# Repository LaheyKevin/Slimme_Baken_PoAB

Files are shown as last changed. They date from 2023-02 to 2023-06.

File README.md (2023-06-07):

# Slimme Baken voor PoAB

## Documentatie

Beste lezer van dit document u kan de documentatie vinden door op volgende link te drukken. [documentatie baken](https://github.com/LaheyKevin/Slimme_Baken_PoAB/blob/main/Documentatie_PoAB_SlimmeBaken.docx)

## Deelnemers

 - Kevin Lahey
 - Quinten Moons

## Bronnen

[Mark down guide](https://www.markdownguide.org/cheat-sheet/)

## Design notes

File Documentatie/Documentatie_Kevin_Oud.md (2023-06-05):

# Slimme Baken voor PoAB

## LoRaWan communicatie

### Wat is LoRaWan
LoRaWan is een protocol dat is ontworpen voor weinig verbuik en een groot bereik. LoRa staat voor "Long Range Radio" en is bedoeld voor IoT devices. Het kan draadloos communiceren met batterij gestuurde "things". Het wordt meestal gebruikt in toepassingen van IoT, het kan in beide richtingen communiceren.

LoRaWan example digikey

### The things network
Voor ons project op te bouwen gaan we gebruik maken van "the things network". Deze organisatie heeft een aantal gateways geplaats die openbaar gebruikt kunnen worden na registratie. Ze hebben ook een "heatmap" waarop er gezien kan worden waar de gateways zijn en/of er verbinding is op bepaalde plaatsen.

1. Aanmaken van een application. In één application kunnen er verschillende devices worden toegevoegd en beheerd worden.
2. Aanmaken van een device. Dit is nodig om onze microcontroller toegang te geven tot de gateways van "the things network".

[The things network](https://www.thethingsnetwork.org/)

[HeatMap ttn](https://ttnmapper.org/heatmap/)

### Verbinding opzetten
We gaan hier verbinding opzetten tussen de microcontroller en "the things network" gateways.

**Aanmaken device**
1. Ga naar applications op de website van ttn
2. Klik op "end devices" en/of "register end device"
3. Vul de volgende instelling in:
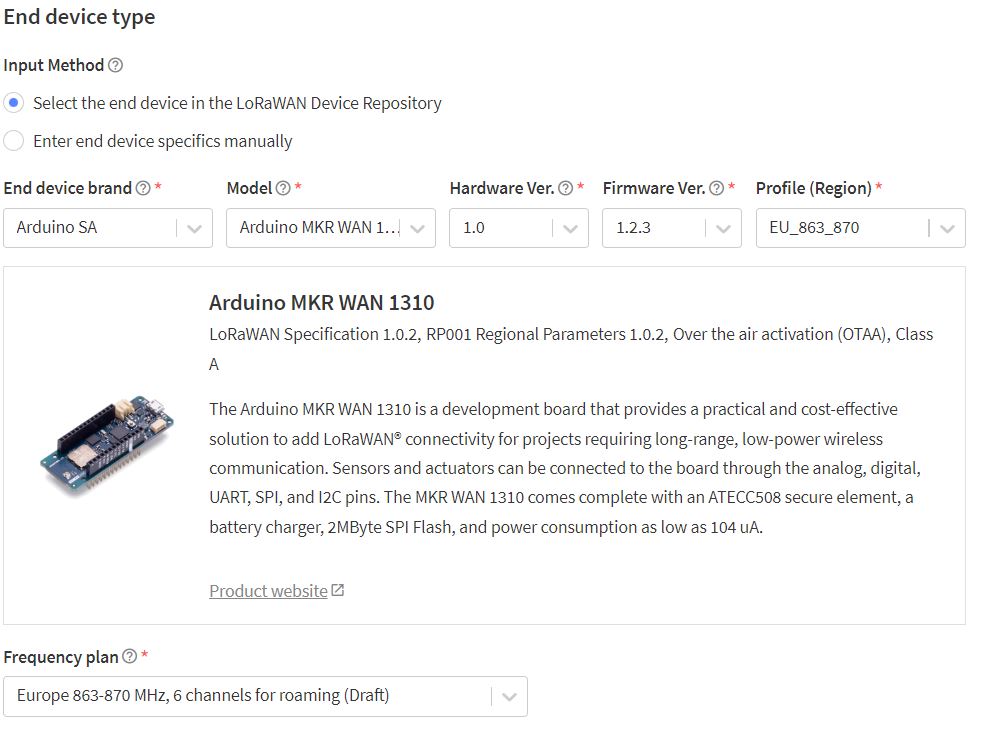
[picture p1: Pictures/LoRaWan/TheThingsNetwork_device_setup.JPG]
TheThingsNetwork device setup

4. Bij "JoinEUI" kan je de waarden invullen die de seriële monitor print bij het uploaden van de voorbeeld code
5. Hierna kan je alle andere keys automatisch generen

**Connecteren**
1. Upload het voorbeeldprogramm in de (MKR WAN 1300)
2. Pas in het programma volgende details aan naar je eigen waarden:
    - devAddr
    - nwkSkey
    - appSkey
3. Hierna zal er op de seriële monitor verschijnen of deze verbinding kan maken
4. Als alles gelukt is kan je op de website zien dat er data wordt ontvangen

**Payload formateren**
Doordat de data die wordt verstuurd over LoRaWan zo klein mogelijk moet zijn is deze gecodeerd. We kunnen instellen hoe deze data gedecodeerd moet worden.
1. Ga naar "End Devices" en selecteer het juiste device
2. Ga naar "Payload formatters"
3. Kies bij "Formatter type": Custom javascript formatter
4. Vul de volgende code in en druk op "save changes"
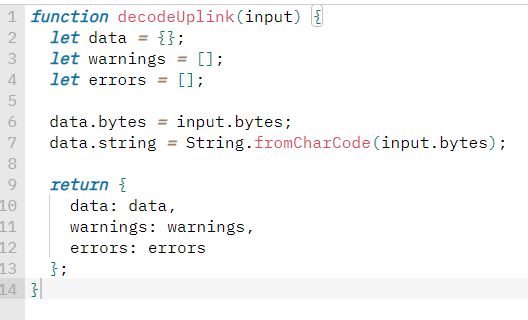
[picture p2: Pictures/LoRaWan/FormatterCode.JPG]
Formatter code

5. Bij live data zie je het volgende:
Data voorbeeld

### Node-red applicatie
Om onze data te visualiseren/zenden gaan we werken met node-red over een mqtt server. Het installeren van dit programma kan via onderstaande link gebeuren. Je kan het programma nadien starten met "node-red" in je cmd, de applicatie vindt je in je browser "http://127.0.0.1:1880".

[Node-RED docs](https://nodered.org/docs/getting-started/local)

### Data µC -> Node-red
Hiervoor zal de data die wordt ontvangen op ttn moeten worden doorgestuurd naar de node-red applicatie. Dit gebeurd via een mqqt server, om deze in te stellen moet je de juiste server configureren in het mqqt blok. Als dit correct gebeurd is zal er connected staan onderaan de blok.

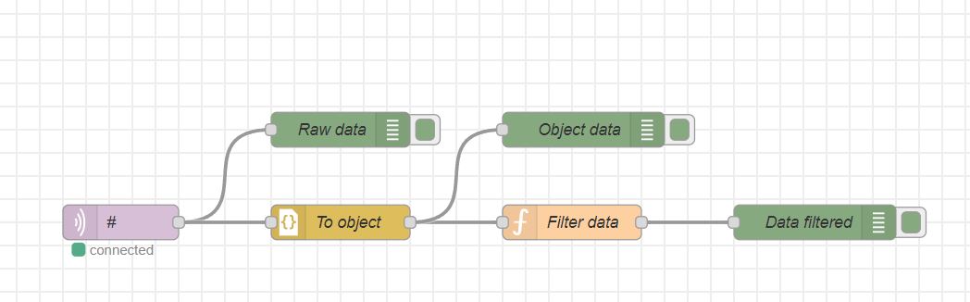
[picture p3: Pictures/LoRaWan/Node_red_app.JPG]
Node-RED applicatie


Schema verduidelijking:
- De paarse blok is de ontvanger "mqqt in"
- Alle groene blokken laten data zien in het "debug" venster
- De gele blok zet data om naar een JavaScript Object
- De filter data block zal deze data filteren en duidelijk weergeven

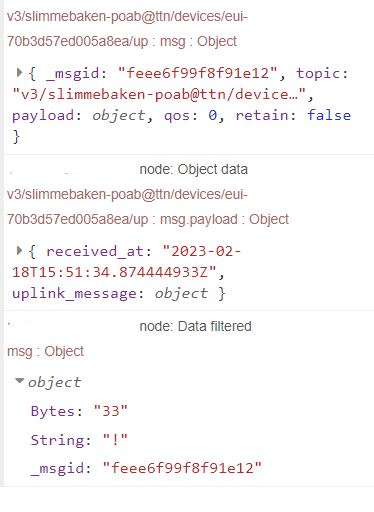
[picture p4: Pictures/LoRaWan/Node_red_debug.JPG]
Node-RED debug vb


### Data Node-red -> µC
Hiervoor zal de data vanaf node-red naar de microcontroller worden gestuurd. Dit zal gebeuren via een mqtt blok in node-red applicatie. je moet de juiste properties instellen die overeen komen met de ttn pagina.

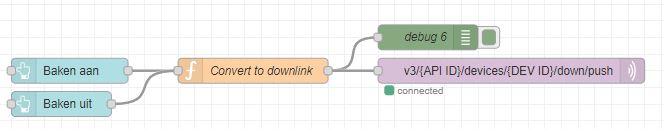
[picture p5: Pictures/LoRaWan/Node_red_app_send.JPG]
Node-RED applicatie


Schema verduidelijking:
- De paarse blok is de ontvanger "mqqt out"
- De groene blok laat data zien in het "debug" venster
- De gele blok zet data om naar een downlink Object
- De blauwe blokken zijn knoppen die data doorgeven

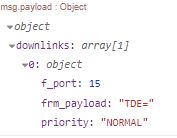
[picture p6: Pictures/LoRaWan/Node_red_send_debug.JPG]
Node-RED applicatie


### LoRaWan data analyze
Voor het verzenden van data over het LoRaWan netwerk is het de bedoeling dat deze berichten zo klein mogelijk zijn. In de code van het project stuur je zogezegd een string door, maar deze wordt geconverteerd naar bytes. Hierdoor moeten we aan de kant van ttn een payload formatter toevoegen die dit terug omzet. Ook hoe groter de string die we sturen hoe langer de "uplink" tijd zal zijn. Hierdoor hebben wij volgende keuzes gemaakt omtrent onze data.

- Berichten opdelen in 3 mode's vanaf de microcontroller
    - Device id:0
        - Bevat het id van de device. We sturen dit mee wanneer de microcontroller opstart zodat deze kan worden toegevoegd in een databank aan de ontvanger.
    - Lamp data:1
        - Bevat of de lampen aan of uit zijn.
        - Bevat foutmeldingen vanuit de baken.
    - GPS locatie:2
        - De locatie waar de baken zich bevindt moet maar 1 keer worden doorgestuurd zodat er geen overload is.

Alle berichten die worden verzonden vanaf de microcontroller worden vooraf gegaan met een identiefier en hierna de mode. Hierdoor kan er een onderscheid worden gemaakt tussen de 3 soorten berichten.

Voorbeeld berichten:

0. DEVid:0
1. DEVid:1:L1:L2:L3:Status
2. DEVid:2:Lat:Lon

### LoRaWan klassen analyze
Binnen LoRaWan bestaan er verschillende klassen. Elke klassen heeft verschillende voordelen en nadelen, we overlopen de 3 klassen hieronder.

1. Klasse A
    - Enkel de end devices kunnen berichten initiëren over het netwerk. Nadat een end device een uplink bericht heeft verzonden worden er 2 recieve windows geopend waarop het end device kan ontvangen.
    
    Klasse A
2. Klasse B
    - Klasse B heeft de zelfde functionaliteiten als klasse A. Ook is het mogelijk om bij klasse B beacons in te stellen via de gateway. Deze gateway zal dan om de zoveel tijd een signaal sturen naar het end device wat hierop een recieve window opent.
    
    Klasse B
3. Klasse C
    - Klasse C is een verdere versie van klasse A doordat de recieve windows open blijven. Hierdoor is het mogelijk om naar het end device te sturen zonder dat deze eerst een uplink moet sturen.
    
    Klasse C

Vergelijking
- Klasse B
    - Deze klasse wordt niet ondersteund door de MKR WAN 1300. We gaan deze niet gebruiken
- Klasse A vs C
    - Klasse C laat ons toe om berichten te sturen vanuit node-red zonder dat de microcontroller eerst een uplink moet sturen. Het nadeel hiervan is dat klasse C een hoger verbruik heeft dan klasse a.
    - Verbruik
        - Klasse A = 0.025A
        - Klasse B = 0.036A

[TTN klassen](https://www.thethingsnetwork.org/docs/lorawan/classes/)

### Node-red data ophalen/invoegen vanuit een database
Om de data te kunnen opslaan gaan we dit doen met een SQL database. De database die we gebruiken vindt u hier:

[Database bakens](https://github.com/LaheyKevin/Slimme_Baken_PoAB/tree/main/LoRaWan/Node-red/DB.sql)

Doordat we verschillende data formaten doorsturen kunnen we dit opdelen in 3 gedeeltes.
- Identifier toevoegen aan database
    - Bij het opstarten van een baken zal er altijd een bericht worden gestuurd met de identiefier in. Hierop kan men ook zien als een baken niet opstart.
    - `"INSERT INTO bakens (id, last_ms) VALUES ('" + id + "','" + Date.now() + "') ON DUPLICATE KEY UPDATE id='" + id + "',last_ms='" + Date.now() + "'"`
    - In bovestaande lijn zal er in de SQL database worden geken of er al een id bestaat. Als dit bestaat wordt deze geupdate met de huidige tijd anders wordt er een nieuw statement aangemaakt.
- Data updaten in de database
    - Dit wordt om een bepaalde tijd verstuurd. Dit bevat de data over de lampen en eventuele errors
    - `"UPDATE bakens SET lamp1=" + L1 + ",lamp2=" + L2 + ",lamp3=" + L3 + ",status_code=" + Error + ",last_ms=" + Date.now() + " WHERE id='"+id+"'"`
    - In bovestaande lijn zal er in de SQL databse de lijn worden geupdate waar het id = id.
- GPS updaten in de database
    - Aangezien de bakens op een statische plaats staan moet dit niet geupdate worden. We kiezen ervoor om dit toch elke dag te updaten.
    - `"UPDATE bakens SET lat=" + Lat + ", lon=," + Lon + " last_ms=" + Date.now() + " WHERE id='" + id + "'"`
    - In bovestaande lijn zal er in de SQL database de lijn worden geupdate waar het id = id.
- Node-RED DB

Data ophalen uit de database.
- We halen alle data uit de tabel op
    - `"SELECT * from bakens"`
    - Node-RED DB

### Node-red data weergeven vanuit de DB a.d.h.v. een dropdown
Om de data die opgehaald is vanuit de database te visualiseren maken we gebruik van het node-red dashboard.

We maken gebruik van een dropdown menu. Alle data die hieraan wordt meegegeven via "msg.options" zal een item voorstellen.
- Omdat we enkel uit de id's willen kunnen kiezen van de bakens gaan we deze in een list plaatsen.
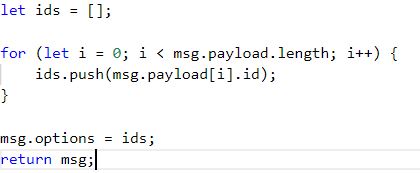
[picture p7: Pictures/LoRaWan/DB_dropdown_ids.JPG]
Node-RED dropdown
    - 
    - We maken een variable waarin we alle id's toevoegen doordat we door de data loopen en elke keer het id eruit halen. Hierna voegen we ze toe aan de options key van het msg object.
- Het dropdown menu geeft het gekozen id weer in "msg.payload". Hiermee kunnen we de aanvullende data uit de database halen.
    - `"SELECT * FROM bakens WHERE id = '" + msg.payload + "'"`
    - We selecteren de correcte rij uit de databse waarin het id overeenkomt met het gekozen id.
- Als we de data hebben uit de DB kunnen we deze in text node's plaatsen zodat deze zichtbaar worden in het dashboard.
    - `{{msg.payload[0].id}}`
    - De bovenstaande lijn laat zien hoe we in een text node data uit de payload kunnen halen.

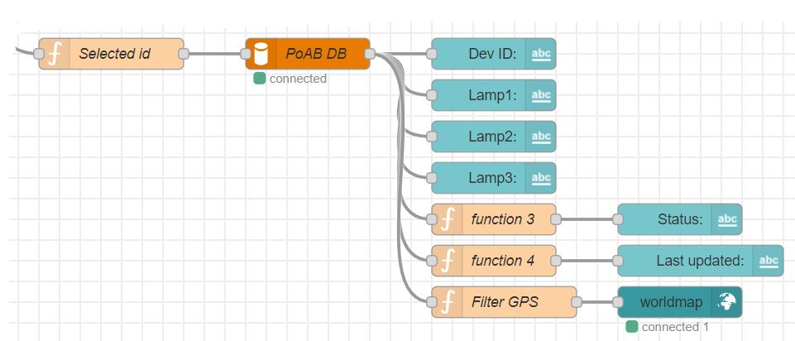
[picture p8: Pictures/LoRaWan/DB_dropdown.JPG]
Node-RED dropdown
- 

### Node-red status codes creëren
Om aan te geven of de baken nog correct werkt zullen we gebruik maken van status codes.

Doordat we 3 leds hebben zouden we per situatie een ander getal kunnen doorsturen. Maar als we gebruik maken van een binaire code die elke led voorstel gaat dit met één byte. Hierdoor moeten we ook minder data versturen over LoRaWan.

- Een byte bestaat uit 4 bits: 0000
    - De eerste 3 bits gebruiken we om de status van de lampen door te geven. 
        - Als één van deze bits hoog is dan wilt dit zeggen dat deze baken niet brand.
    - De laatste bit gebruiken we om aan te geven of er al een controle is uitgevoerd.
        - Als dit 0 is wilt dit zeggen dat de baken nog geen controle heeft uitgevoerd.
        - Als dit 1 is wilt dit zeggen dat de controle is uitgevoerd op de baken.
    - Voorbeeld:
        - 0000 = Er is nog geen controle uitgevoerd op de baken
        - 1001 = De eerste lamp zal niet branden en er is een controle uitgevoerd

- Node-red
    - We krijgen via LoRaWan nog steeds een int doorgestuurd. Deze zetten we om naar een binair getal waaruit we dan per karakter kunnen kijken of er iets mis is.
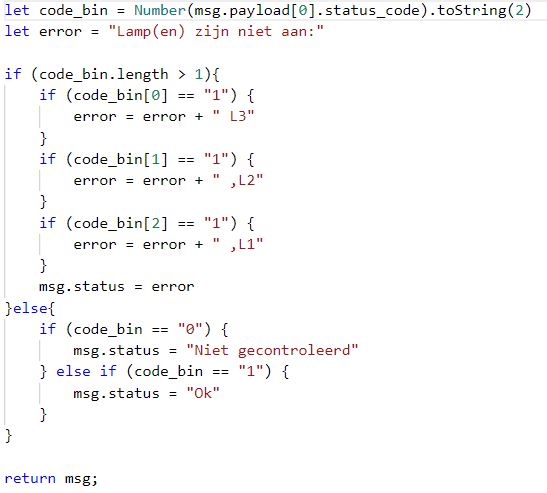
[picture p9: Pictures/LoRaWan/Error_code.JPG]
Node-red status
    - 

### Dashboard opstellen
Met Node-red gaan we onze data visualiseren. Hieronder ziet u een voorbeeld van het huidig dashboard.

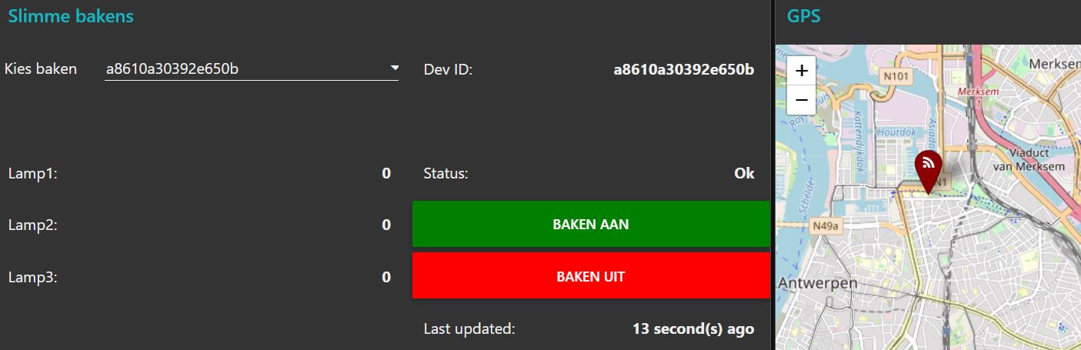
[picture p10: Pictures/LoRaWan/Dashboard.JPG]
Node-red dashboard


[Node-red flow.json](https://github.com/LaheyKevin/Slimme_Baken_PoAB/blob/main/LoRaWan/Node-red/flows.json)

## Programma
Het programma voor de arduino MKR WAN 1300

[Arduino code](https://github.com/LaheyKevin/Slimme_Baken_PoAB/blob/main/LoRaWan/Programma/Programma.ino)

## Lampen aansturen

### Onderzoek relais/ssr/mosfet
Hier gaan we na welke component we het beste kunnen gebruiken voor het aansturen van de lampen.

- Relais
    - Een relais is een elektromagneetische schakelaar. Deze bestaat uit een spoel, het anker en een plaat ijzer dat wordt aangetrokken door de magneet.
- SSR (solid state relais)
    - Een SSR of halfgeleiderrerlais is principeel gezien geen relais want er zijn geef bewegende delen. Deze bestaat uit een interne led, fototransisor en transistor/scr/triac.
- Mosfet
    - De mosfet is een bepaald type veldeffecttransistor (FET). Deze bestaat uit verschillende lagen (metaal, oxide, semiconductor).
    
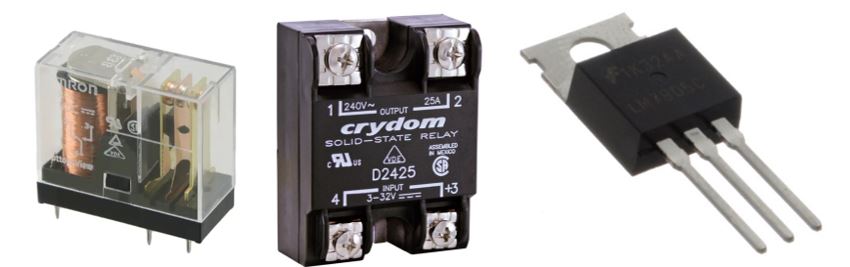
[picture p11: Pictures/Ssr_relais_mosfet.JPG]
Relais_SSR_Mosfet


Vergelijking
- Relais vs SSR
    - Een relais maakt gebruik van mechanische contacten waardoor hier bewegende delen zijn en vonken kunnen onstaan. Bij een srr is dit een logische schakeling waardoor hier geen vonken of bewegende delen zijn. Hierdoor is de levensduur van de srr langer dan een relais.
- SSR vs Mosfet
    - Bij een mosfet moet er nog een extra weerstanden worden geplaats voor de aansturing ervan, dit is niet nodig bij een ssr.

Besluit
- We kienzen voor een SSR
    - Dit doordat deze geen bewegende delen heeft en een relais wel. Ook moet hier minder extra componenten worden toegevoegd om deze aan te sturen.

[Relais wiki](https://nl.wikipedia.org/wiki/Relais)

[SSR wiki](https://nl.wikipedia.org/wiki/Halfgeleiderrelais)

[Mosfet wiki](https://nl.wikipedia.org/wiki/MOSFET)

### Aansturen verbruiker
De module die we gaan aansturen is de [AQY211EHAZ](https://be.farnell.com/panasonic/aqy211ehaz/mosfet-relay-spst-1a-30v-dip-4/dp/3881433). Deze kan worden aangestuurd door onze µC en laat hoge stromen door. 

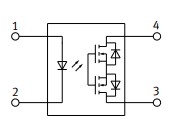
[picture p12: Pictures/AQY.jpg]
Schema AQY


Pinout:
1. Led input
2. Led output
3. Vermogen input
4. Vermogen output

De led kan maximaal 50mA aan en een reverse voltage van 5V. De vermogen uitgang kan 30V en 1A aan.

Berekening voor de weerstand van da ding
3.3V
Typical 1.2mA-3mA

2.21mA met 1K
3.18mA met 680

https://hydrosphere.co.uk/products/sabik-sc-110/
https://octopart.com/lxm2-pl01-0000-lumileds-11546034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
https://octopart.com/datasheet/lxm2-pl01-0000-lumileds-11546034

## Metingen die uitgevoerd worden

### Stroom meting ACS712

### Spanning/stroom meting INA219
Met deze component gaan we de spanning en stroom meten over de gehele schakeling. Het bordje beschikt over I2C communicatie waarmee de MKR WAN 1300 kan comuniceren. Om de component uit te lezen maken we gebruik van de [Adafruit_INA219](https://github.com/adafruit/Adafruit_INA219) library. Deze library laat ons toe om snel data op te halen vanuit de sensor.

Hoe library te gebruiken:
1. Library defineren bovenaan de code

    `#include <Adafruit_INA219.h>`

    `Adafruit_INA219 ina219;`
2. De sensor initialiseren in de setup

    `ina219.begin()`
3. De waardes uitlezen in de loop

    `shuntvoltage = ina219.getShuntVoltage_mV();`

    `busvoltage = ina219.getBusVoltage_V();`

    `current_mA = ina219.getCurrent_mA();`

    `power_mW = ina219.getPower_mW();`

    `loadvoltage = busvoltage + (shuntvoltage / 1000);`
    
4. Resultaat

COM poort resultaat

INA219 breakout bordje

## Bestellijst
In onderstaande lijst zijn alle componeten opgelijst die we nodig hebben voor de uitwerking van dit project. In de bestellijst V2 zitten alle componeten dubbel omdat dit voor 2 groepen is.

[Bestellijst V1 exel](https://github.com/LaheyKevin/Slimme_Baken_PoAB/blob/main/Materiaal/BestellijstV1.xlsx)
[Bestellijst V2 exel](https://github.com/LaheyKevin/Slimme_Baken_PoAB/blob/main/Materiaal/BestellijstV2.xlsx)

### Connectoren
IP 68, connectoren om de bak te verbinden met de lampen. Ze verschillen in diameter. Connectie stukken staat in vaak samen gekocht:
tabel met specificaties moet hier komen enzo

1. https://www.conrad.be/nl/p/weipu-sp2110-p-2-i-ronde-connector-stekker-recht-serie-ronde-connectors-sp21-totaal-aantal-polen-2-1-stuk-s-736559.html
2. https://www.conrad.be/nl/p/weipu-sp2112-s-2-ronde-connector-bus-inbouw-serie-ronde-connectors-sp21-totaal-aantal-polen-2-1-stuk-s-738454.html

https://www.visser-assen.nl/blog-en-nieuws/aantal-amperes-en-draaddikte-van-krachtstroomkabels

https://datasheetspdf.com/datasheet/AQY211EHAZ.html

## PCB
1. Schema
2. PCB

## Referentie links
[FLWSB-SAMDaaNo21](https://github.com/DaanDekoningKrekels/FLWSB-SAMDaaNo21)

[ArduinoCore-samd](https://github.com/DaanDekoningKrekels/ArduinoCore-samd)

[The things network docs](https://www.thethingsindustries.com/docs/)

[Node-RED LoRaWan](https://www.thethingsindustries.com/docs/integrations/node-red/)

[Markdown guide](https://www.markdownguide.org/cheat-sheet/)

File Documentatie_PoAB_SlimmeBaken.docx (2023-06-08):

# Toegepaste Informatica/ Elektronica-ICT

# Documentatie: Slimme bakenverlichting

Ondersteund door de

# AP Hogeschool

En uitgevoerd op en begeleid door het bedrijf

# Port of Antwerp - Bruges

# Kevin Lahey & Quinten Moons

Specialisatie IT & Internet of Things

Academiejaar 2023-2024
Mentor: Dirk Van Merode 2de semester
Maarten Luyts, Marijn De Pooter en Sam Van Battel

# Projectdefinitie

## Samenvatting

Baken verlichtingen dienen ervoor om schippers veilig te laten varen zonder dat deze een aanvaring krijgen. Daarom is het doel van het project om de huidige bakens in de PoAB slimmer te maken. De huidige bakens hebben op dit moment geen mogelijkheid tot verbinding met het LoRaWan netwerk. Er is ook geen microcontroller aanwezig waardoor er geen data kan verstuurd of ontvangen worden, hierdoor kunnen de lichten niet vanop afstand geregeld worden. En is er geen controle over of deze bakens dag en/of nacht branden.

Door de bakens te voorzien van een LoRaWan ontvanger/zender en een microcontroller kunnen we de volgende functies bekomen: de baken vanop afstand kunnen aan/uit zetten, de baken moet weergeven of de led defect is of niet, de gps-locatie zal doorgegeven kunnen worden. Voor de toekomst is het mogelijk om extra sensoren aan te sluiten op de PCB. Zodat er later bv. luchtvervuiling gemeten kan worden. De batterij van de baken zal worden opgeladen a.d.h.v. een zonnepaneel.

## Doelstelling

Voor dit project moeten we:

- Een slimme baken maken die communiceert met het LoRaWan netwerk en de veiligheid in de haven maximaliseert.
- De conditiestaat uitlezen van een baken
  - Aan/uit per armatuur
  - Batterijstatus (capaciteit)
- Automatisch foutmeldingen genereren.
  - Melding wanneer een armatuur niet oplicht.
  - Melding wanneer de batterij onder zijn gemiddelde waarde komt.
- Informatie over zijn gps-locatie geven.
- De baken moet kunnen detecteren of er één of meerdere armaturen niet oplichten wanneer deze horen opgelicht te zijn.
- De bakens vanop afstand kunnen bedienen zodat deze manueel aan/uit gezet kunnen worden.
- De capacitieve waarde van de batterij moet worden weergegeven in procent.
- De batterij van de baken laten opladen a.d.h.v. een zonnepaneel.
- De baken toekomstgericht voorzien door meerdere aansluitingen te voorzien voor eventuele extra sensoren/actuatoren

## Visie eindproduct

Het eindproduct van dit project zal er uitzien als een prototype dat op een externe locatie kan geplaats worden. Dit prototype zal verbinding kunnen maken met het LoRaWan netwerk. Via deze verbinding zullen er 3 armaturen kunnen worden aangestuurd. Het prototype zal kunnen controleren of deze lampen aan of uit zijn, de locatie ophalen en de batterijstatus doorgeven. Het prototype zal gevoed worden door een batterij die via een zonnepaneel opgeladen zal worden.

# Hardware

## Blokdiagram

Algemeen:

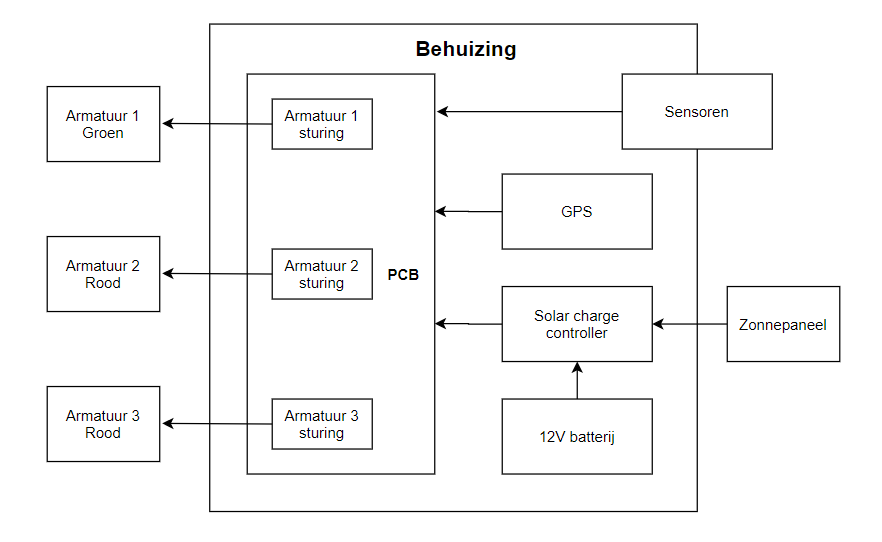
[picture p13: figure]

PCB:

Sensoren:

Armatuur sturing:

## Componenten

Blok | Specificatie | Aantal | Prijs | Link
Arduino MKR WAN 1300 | Vcc = 5V-5.5V CPU = SAMD21 I2C, UART, SPI, LoRa | 1 | € 43.0 | MKR WAN (https://elektronicavoorjou.nl/product/arduino-mkr-wan-1300-met-ufl-connector/)
5V regulator | Uin = 5V-18V Uout = 5V | 1 | € 0.64 | L7805CV (https://www.digikey.be/nl/products/detail/stmicroelectronics/L7805CV/585964)
Batterij meting | Vcc = 3V-5.5V Umax = 26V Imax = 3.2A I2C | 1 | € 4.13 | INA219 (https://www.tinytronics.nl/shop/nl/sensoren/stroom-spanning/ina219-i2c-dc-stroom-en-spanningsmeter-3.2a-module)
Licht sensor | Vcc = 4-6V Sensitivity = 570nm | 4 | € 1.31 | TEMT6000X01 (https://www.digikey.be/nl/products/detail/vishay-semiconductor-opto-division/TEMT6000X01/1681189)
Stroom meting | Vcc = 4.5V-5.5V Icc = 13mA Imax = 5A Sensitivity = 185 mV/A | 3 | € 3.54 | ACS712-05B (https://www.digikey.be/nl/products/detail/allegro-microsystems/ACS712ELCTR-05B-T/1284593)
Led driver | Iout = 500 mA Vout = 40V | 3 | € 0.34 | BCR411UW6-7 (https://be.farnell.com/diodes-inc/bcr421uw6-7/led-driver-aec-q101-linear-sot/dp/3127238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)
Mosfet relais | Led current = 3 mA Umax = 30V Imax = 1A | 3 | € 3.44 | AQY211EHAZ (https://be.farnell.com/panasonic/aqy211ehaz/mosfet-relay-spst-1a-30v-dip-4/dp/3881433)
I2C ADC module | Vcc = 2V-5.5V 16-bit ADC I2C | 1 | € 5.50 | ADS1115 16-bit ADC I2C Module (https://www.tinytronics.nl/shop/nl/sensoren/stroom-spanning/ads1115-16-bit-adc-i2c-module-4-kanaals)
GPS | Vcc = 3.3V-5V Icc = 35 mA UART = 9600 | 1 | € 19.41 | NEO-7M (https://www.bol.com/be/nl/p/otronic-neo-7m-gps-module-met-antenne/9300000097011732/)
Solar charge controller | Range = 12V, 24V, 48V I = 10A | 1 | € 71.9 | Victron Energy (https://www.conrad.be/nl/p/victron-energy-blue-solar-pwm-lcd-usb-solar-laadregelaar-pwm-12-v-24-v-10-a-2497145.html)
Batterij | Vout = 12V Capacity = 50 Ah Weight = 15.1 kg | 1 | € 169.9 | WP50-12NE (https://www.conrad.be/nl/p/long-wp50-12ne-loodaccu-12-v-50-ah-loodvlies-agm-b-x-h-x-d-199-x-171-x-166-mm-m6-schroefaansluiting-cyclusbestendig-2368959.html)

### Arduino MKR WAN 1300

We gaan gebruik maken van de Arduino MKR WAN 1300. Dit bord is op de markt gebracht door Arduino om een praktische en lage kost oplossing te voorzien met een laag verbruik. De processor aanwezig op het bord is de “Arm Cortex-M0 32 bit SAMD21”. We hebben dit bord gekozen omdat deze te programmeren is met de Arduino IDE waarin we al ervaring hebben. Het bordje is voorzien van de mogelijkheid om te verbinden met een bestaand LoRaWan netwerk. Dit netwerk is aanwezig in de haven, LoRaWan wordt later meer in detail uitgelegd. De microcontroller werkt op 3.3V. Hij heeft 14 digitale pinnen en 6 analoge pinnen. Het bordje kan gevoed worden met 5V doordat deze een onboard regulator heeft.

Gebruik:

- Installeren van de correcte board manager
  1. Arduino IDE
  2. Tools -> Board: -> Boards Manager
  3. Type in “samd”
  4. Installeer “Arduino SAMD Boards (32-bits ARM Cortex-M0+)”

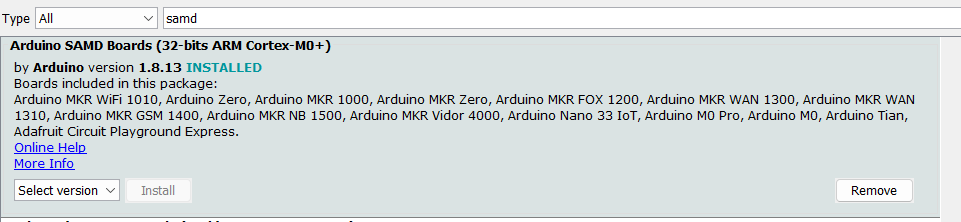
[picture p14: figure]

- Selecteren van de juiste board manager
  5. Arduino IDE
  6. Tools -> Board: -> Arduino SAMD -> Arduino MKR WAN 1300
- Werking uittesten
  7. We gaan de ingebouwde led aan en uit laten gaan

### 5V regulator

Op de PCB gaan we gebruik maken van een 5V regulator de L7805CV om de nodige component correct te voeden. De ingang spanning van de PCB is 12V die afkomstig is van de solar charge controller.

De volgende componenten hebben 5V voeding nodig.

- MKR WAN 1300 – microcontroller
- I2C ADC Module – analog digital converter I2C
- ACS712 – stroom meting

Aansluitingen L7805CV.

- Input = 5V-18V
- Ground = grond
- Output = 5V

### Batterij meting

Om te kunnen bepalen hoeveel percentage dat de batterij nog heeft moeten we deze kunnen uitmeten. We gaan dit doen met het INA219 bord. Deze beschikt over I2C communicatie waarmee de MKR WAN 1300 kan communiceren. Om de component uit te lezen maken we gebruik van de “Adafruit_INA219” library. Deze library laat ons toe om de data direct te verkrijgen zonder extra instellingen te moeten uitvoeren.

Gebruik van de INA219.

- Library definiëren bovenaan de code
- De library initialiseren in de setup
- De waardes ophalen in de loop
- Resultaat

### Licht sensor

Als licht sensor voor deze toepassing hebben we gekozen voor de TEMT6000X01. De licht sensor wordt op 2 plaatsen in het project gebruikt. Het wordt gebruikt om te controleren of de armaturen lichten effectief licht geven als deze worden aangestuurd. Ook word er één licht sensor gebruikt om de omgevingslicht te meten. Hiermee kunnen we bepalen of het nacht of dag is. Deze sensor zal op een PCB worden geplaats zodat die dicht bij de lampen kan geplaats worden.

Gebruik TEMT6000X01 met MKR WAN 1300.

- Aansluitingen
  - Vcc = 3.3V
  - Sig = A0 (analoge pin 0)
  - GND = grond
- Inlezen van de sensor

### Stroom meting

We gaan gebruik maken van een stroom meting via de ACS712. Dit omdat we zo een extra controle kunnen uitvoeren of de armaturen oplichten of niet. Voor elk armatuur staat er een stroom meting die verbonden is met de I2C ADC module. Dit zorgt ervoor dat we de stroom per armatuur kunnen inlezen.

Probleem voeding ACS712

- De ACS712 heeft 5V nodig als voeding om een correcte werking te hebben. Hierdoor zal de uitgaande spanning liggen tussen 5V en 0V. Het probleem is dat de MKR WAN 1300 maar spanningen aan kan van 3.3V-0V. Hierdoor zou het dus kunnen als de ACS712 een grote stroom meet dit resulteert in een hoge ADC waarde waardoor de pinnen van de MKR WAN 1300 stuk zouden gaan.
- Oplossing
  - We maken gebruik van een I2C ADC module. Deze module werkt ook op 5V maar doordat deze communiceert over I2C met de MKR WAN 1300 is er geen probleem dat er 5V op de pinnen van de MKR WAN 1300 komen te staan. Hierdoor zijn de 3 ACS712 verbonden met de I2C ADC module.

### Led driver

De led driver BCR412UW6-7 zal ervoor zorgen dat de armaturen een correcte stroom krijgen. Als er geen led driver aanwezig is zullen de leds binnenin de armaturen stuk gaan. Wij hebben gekozen voor een stroom van ± 120 mA.

Aansluitingen BCR412UW6-7

- EN = enable pin deze wordt gebruikt om de IC te gebruiken
- OUT = de aansluiting vanaf de uitgang van de led naar gnd
- Rext = externe weerstand die het stroom niveau bepaalt
- GND = grond

Alternatieven led driver

- Vermogen weerstand
  - Wij hebben hier niet voor gekozen doordat deze warm worden en hierdoor veel energie verbruikt.

### Mosfet relais

De mosfet relais AQY211EHAZ wordt gebruikt om de led driver te schakelen. Die ervoor zorgt dan de armaturen aan of uit gaan. Deze is aangesloten op een uitgang pin van de MKR WAN 1300.

Waarom gebruiken we een mosfet relais?

- Oorspronkelijk gingen we niet werken met een led driver, waardoor er een grote stroom gestuurd moest worden door een andere component. Om deze grote stroom te schakelen zijn we opzoek gegaan naar verschillende mogelijkheden. Omdat de PCB al getekend was met de mosfet relais is deze aanwezig in het huidige prototype.

Onderzoek voor het aansturen van grote verbruikers. In dit gedeelte gaan we na welke component we het beste kunnen gebruiken voor het aansturen van de lampen.

- Relais
  - Een relais is een elektromagnetische schakelaar. Deze bestaat uit een spoel, het anker en een plaat ijzer dat wordt aangetrokken door de magneet.
- SSR (solid state relais)
  - Een SSR of halfgeleiderrelais is principieel gezien geen relais want er zijn geen bewegende delen. Deze bestaat ui een interne led, fototransistor en een transistor/scr/triac.
- Mosfet
  - De mosfet is een bepaald type veld effecttransistor (FET). Deze bestaat uit verschillende lagen (metaal, oxide, semiconductor)


- Relais vs. SSR
  - Een relais maakt gebruik van mechanische contacten waardoor hier bewegende delen zijn en vonken kunnen ontstaan. Bij een ssr is dit een logische schakeling waardoor hier geen vonken of bewegende delen zijn. Hierdoor is de levensduur van de ssr langer dan een relais.
- SSR vs. Mosfet
  - Bij een mosfet moet er nog een extra weerstand worden geplaats voor de aansturing hiervan, dit is niet nodig bij een ssr.
- Besluit
  - We kiezen voor een SSR
    - Dit doordat deze geen bewegende delen heeft en een relais wel. Ook moet hier minder extra componenten worden toegevoegd om deze aan te sturen.

### I2C ADC Module

Om de analoge waarde van de stroom sensoren in te lezen gaan we gebruik maken van de ADS1115 16-bit I2C module. Deze heeft de mogelijkheid om 4 ingang kanalen aan te sluiten. De module communiceert via I2C met de MKR WAN 1300.

Gebruik ADS1115 met MKR WAN1300.

- We maken gebruik van de ADS1X15 library
- Met volgende code kunnen we de analoge waarde op A0 van de ADS1115 uitlezen.

### GPS

De GPS wordt gebruikt om de huidige locatie op te halen en deze mee te sturen over LoRaWan. We gebruiken de NEO-6M module. De GPS module communiceert met de MKR WAN 1300 via seriële communicatie. De GPS verijst 3.3V om te werken. Voor het aanroepen van de GPS gebruiken we in onze software hardware serial.

Gebruik GPS.

- We maken gebruik van de TinyGPSPlus library
- File -> Examples -> TinyGPSPlus -> FullExample
  - Hiermee kan je testen of de GPS werkt. Hij laat alle informatie zien die er mogelijk is in dit voorbeeld.

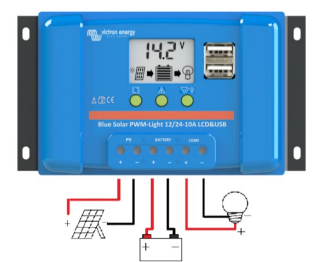
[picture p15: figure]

### Solar Charge Controller

Om de schakeling van stroom te blijven voorzien op een externe locatie hebben we gekozen voor de “Victron Energy Blue-Solar PWM laadregelaar”. Deze zal ervoor zorgen dat de batterij wordt opgeladen aan de hand van het zonnepaneel. En dat de PCB voorzien wordt van 12V. Deze laadregelaar is in het huidige prototype nog niet aanwezig.

### Batterij

We zijn opzoek gegaan naar een batterij die zoveel mogelijk ampère-uur levert en in de behuizing past. We hebben er 1 gekozen die 12V en 50Ah levert. De schakeling zal dus gevoed worden door een externe batterij. Deze wordt aangesloten op de laadregelaar en kan hierdoor worden geladen en de schakeling voeden.

## Theoretische Stroom analyse

TEMT6000X01 x4 20mA x 6V
AQY211EHAZ x3 1A x 5V
ACS712ELCTR-05B-T x3 13mA x 5V
INA219 10mA x 5V
L7805CV 6mA x 5V
Lampen x3 1A x 12V
ADS1115 10mA x 5V
NEO-7M 67mA x 5V
BCR411UW6-7 x3 150mA x 5V

Totaal = 6662mA

6662 * 24h = 159.888mAh = 159,888Ah/ 3 = 53.3Ah

Er kan theoretisch maximum 6,662A door het bordje vloeien, als je dit 24 uur wilt laten branden heb je een batterij van 159,888Ah of drie batterijen van 53,3Ah. De kans dat er 6,662A door het bordje vloeit is vrij klein, dus moet je niet naar een batterij zoeken die voor 24 uur lang deze stroom aan kan. Effectief zal er waarschijnlijk maximum 3A door het bordje vloeien.

## PCB ontwerp prototype

Hieronder vindt u de pcb’s die we hebben gebruikt om het prototype te verwezenlijken. De pcb’s zijn gemaakt door De Wilde Géröme van groep POA1.

### Hoofd PCB

- Componenten
  - MKR WAN 1300 connector
  - ADS1115
  - GPS connector
  - 3x connector sturing armaturen
  - 4x licht sensor connector
  - Voeding connector
- Schema

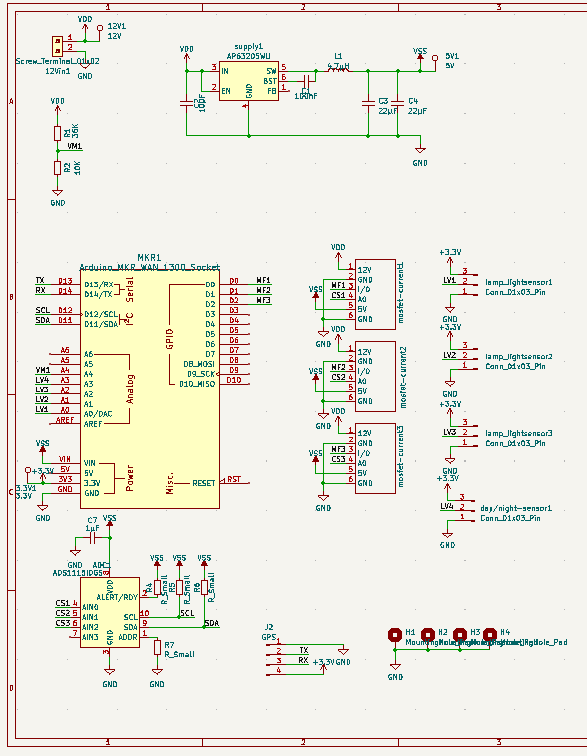
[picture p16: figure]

- PCB

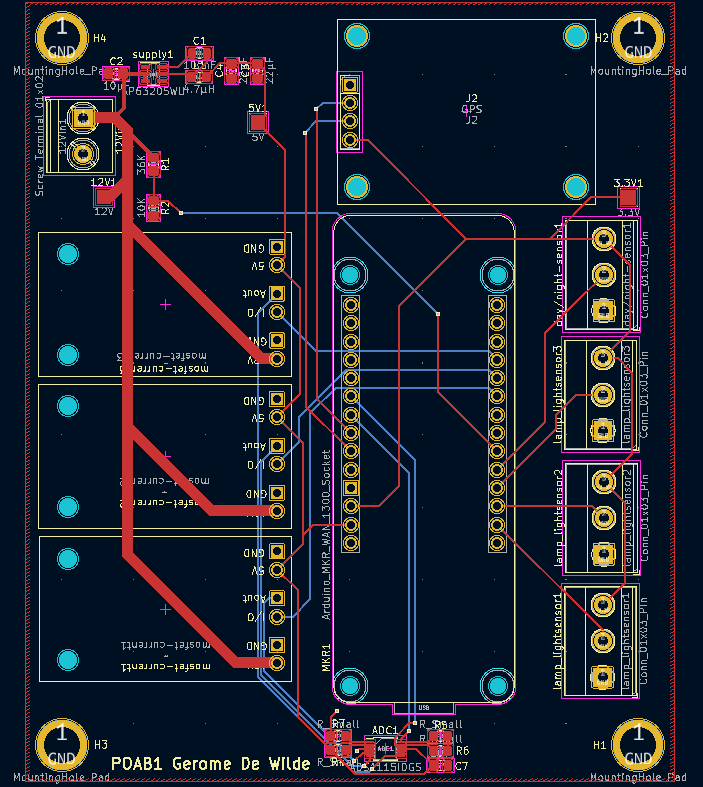
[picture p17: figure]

- 3D

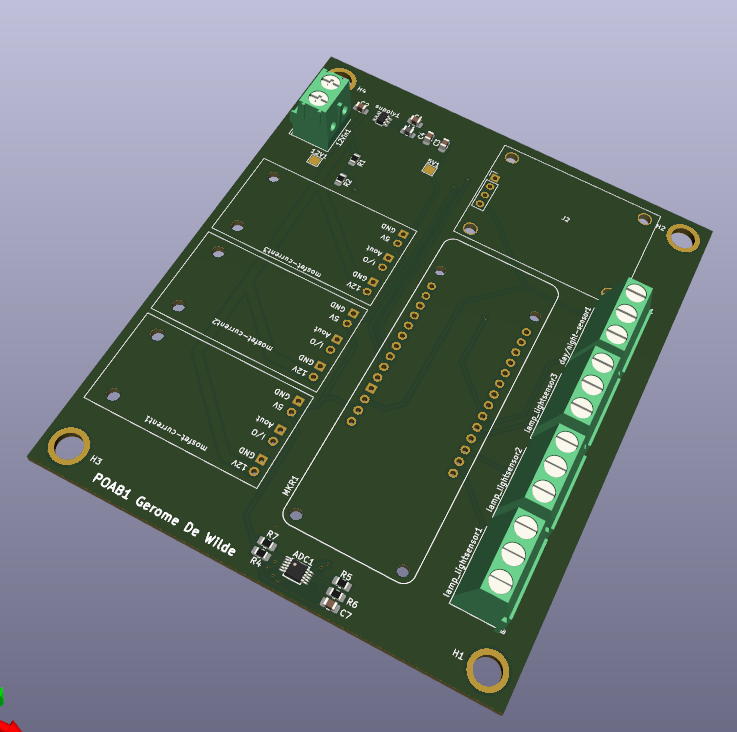
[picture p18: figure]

### Aansturing armatuur PCB

- Componenten
  - Mosfet
  - Led driver
  - ACS712
  - Connector voor armatuur (plus, min)
- Schema

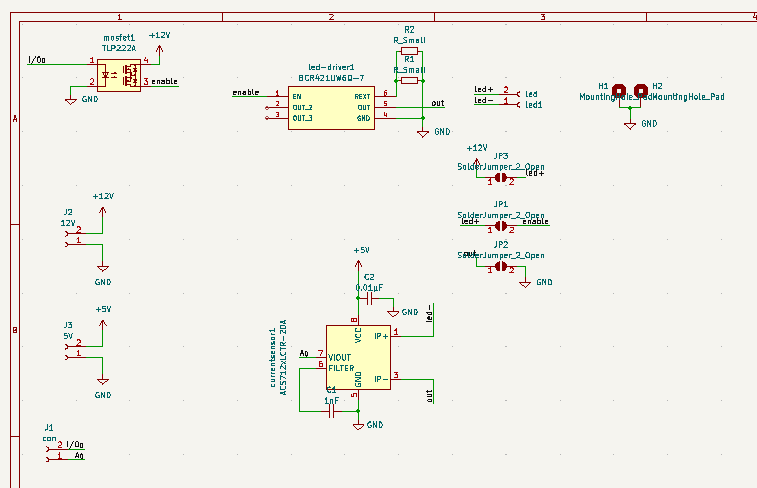
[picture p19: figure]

- PCB

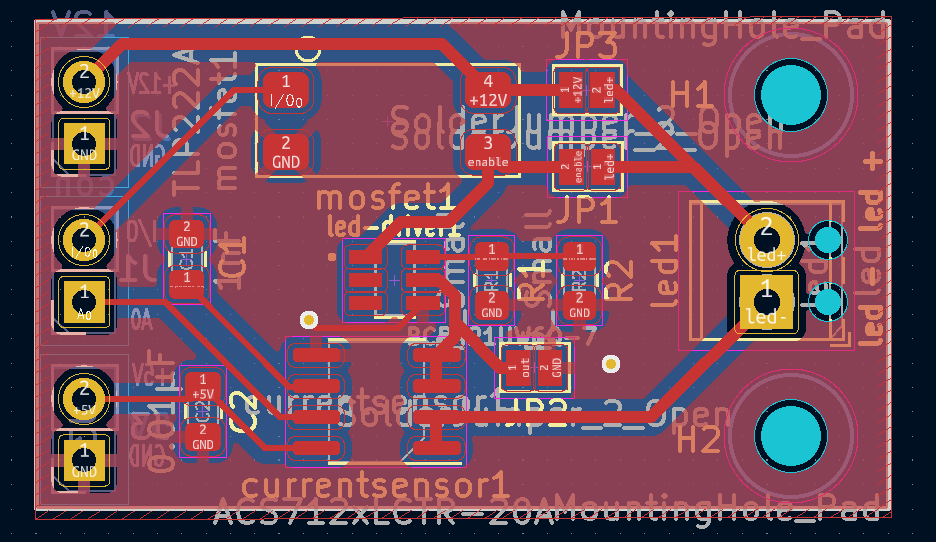
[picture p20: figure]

- 3D

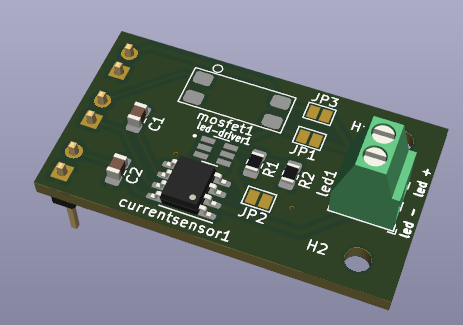
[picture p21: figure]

### Licht sensor PCB

- Componenten
  - TEMT6000
- Schema

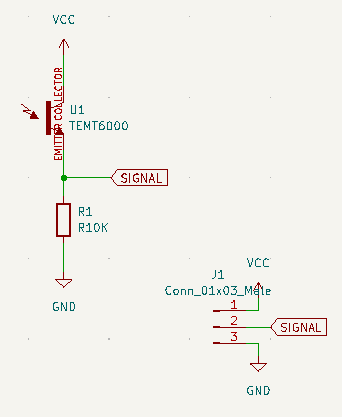
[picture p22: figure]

- PCB

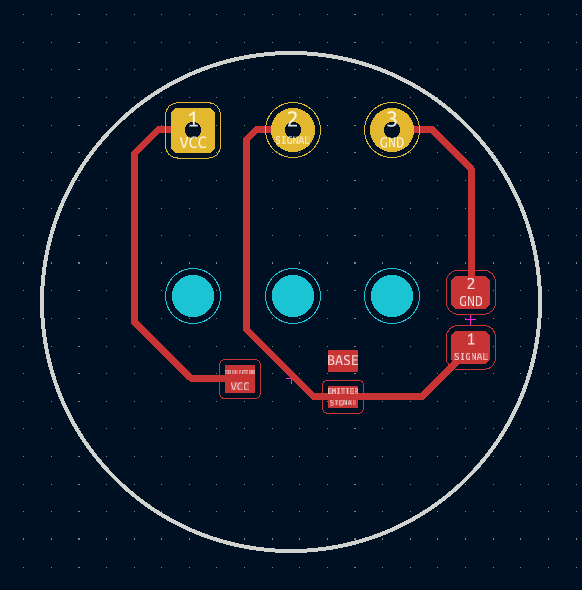
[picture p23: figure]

- 3D

## PCB ontwerp theoretisch

### Hoofd PCB

- Componenten
  - MKR WAN 1300 connector
  - ADS1115
  - GPS connector
  - 4x licht sensor connector
  - Voeding connector
  - 3x Mosfet
  - 3x ACS712
  - 3x lamp connector
  - INA219
  - L7805CV
- Schema

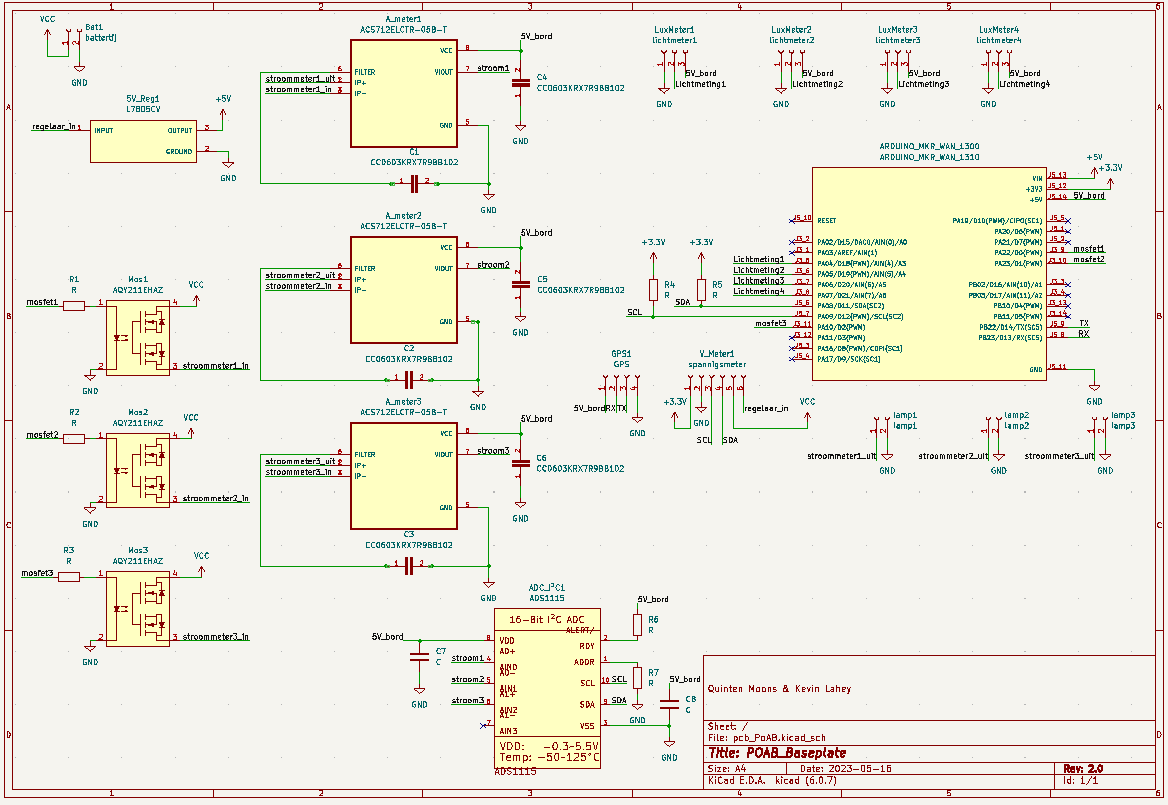
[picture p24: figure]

- PCB
- 3D


### Licht sensor PCB

- Componenten
  - TEMT6000
- Schema


- PCB
- 3D


# Software

## LoRaWan communicatie

### LoRaWan

- Wat is LoRaWan
  - LoRaWan is een protocol dat is ontworpen voor weinig verbruik en een groot bereik. LoRa staat voor “Long Range Radio” en is bedoeld voor IoT devices. Het kan draadloos communiceren met batterij gestuurde “things”. Het wordt meestal gebruikt in toepassingen van IoT, het kan in beide richtingen communiceren


- The things network
  - Voor ons project op te bouwen gaan we gebruik maken van “the things network”. Deze organisatie heeft een aantal gateways geplaatst die openbaar gebruikt kunnen worden na registratie. Ze hebben ook een “heatmap” waarop er gezien kan worden waar de gateways zijn en/of er verbinding is op bepaalde plaatsen.
    - Aanmaken van een application. In één application kunnen er verschillende devices worden toegevoegd en beheerd worden.
    - Aanmaken van een device. Dit is nodig om onze microcontroller toegang te geven tot de gateways van “the things network”.
- Data analyse
  - Voor het verzenden van data over het LoRaWan netwerk is het de bedoeling dat deze berichten zo klein mogelijk zijn. In de code van het project stuur je zogezegd een string door, maar deze wordt geconverteerd naar bytes. Hierdoor moeten we aan de kant van ttn een payload formatter toevoegen die dit terug omzet. Ook hoe groter de string die we versturen hoe langer de “uplink” tijd zal zijn. Hierdoor hebben wij volgende keuzes gemaakt.
  - Berichten opdelen in 3 modes vanaf de microcontroller.
    - Mode 0 = Startup/power on
      - Hierbij weten we aan de ontvangende kant dat de microcontroller is opgestart en klaar voor gebruik.
    - Mode 1 = Data
      - Bevat of de lampen aan of uit zijn
      - Bevat de huidige spanning waarde van de batterij
      - Bevat de status code
    - Mode 2 = GPS
      - De locatie waar de baken zich bevindt moet maar 1 keer worden doorgestuurd. Hierdoor is dit een aparte modus, dan kan er geen “overload” ontstaan.
  - Om de berichten te herkennen aan de ontvangende kant zal er altijd een 0-1-2 worden meegestuurd om aan te tonen wat voor bericht het is. De identiefier van de microcontroller moet niet mee worden gestuurd omdat die standaard in het bericht zit dat wordt ontvangen.
  - Voorbeeld berichten
    - 0:0
    - 1:L1:L2:L3:Bat:status
    - 2:Lat:Lon
- Klassen analyse
  - Binnen LoRaWan bestaan er verschillende klassen. Elke klassen heeft verschillende voordelen en nadelen, we overlopen de 3 klassen hieronder.
    - Klasse A
      - Enkel de end devices kunnen berichten initeren over het netwerk. Nadat een end device een uplink bericht heeft verzonden, worden er 2 recieve windows geopend waarop het end device data kan ontvangen.
    - Klasse B
      - Klasse B heeft dezelfde functionaliteiten als klasse A. Ook is het mogelijk om bij klasse B beacons in te stellen via de gateway. Deze gateway zal dan om de zoveel tijd een signaal sturen naar het end device, waarop het end device een recieve window opent.


    - Klasse C
      - Klasse C is een verdere versie van klasse A doordat de recieve windows open blijven. Hierdoor is het mogelijk om naar het end device te sturen zonder dat deze eerst een uplink moet sturen.
  - Vergelijking van de klasse
    - Klasse B
      - Deze klassen wordt niet ondersteund door de MKR WAN 1300. We kunnen deze niet gebruiken.
    - Klasse A vs. C
      - Klasse C laat ons toe om berichten te sturen vanuit node-red, zonder dat de microcontroller eerst een uplink moet sturen. Het nadeel hiervan is dat klasse C een hoger stroom verbruik heeft dan klasse A
      - Verbruik
        - Klasse A = 25 mA
        - Klasse C = 36 mA

### Verbinding LoRaWan

In dit gedeelte gaan we verbinden opzetten tussen de arduino MKR WAN 1300 en de “the things network” gateways.

- Aanmaken device
  - Ga naar applications op de website van ttn
  - Klik op “end devices” en /of “register end device”
  - Vul de volgende instellingen in:


  - Bij “JoinEUI” kan je de waarden invullen die de seriële monitor print bij het uploaden van de voorbeeld code. Deze code is te vinden op volgende locatie: File -> Examples -> MKR WAN -> FirstConfiguration.
  - Hierna kan je alle andere keys automatisch genereren
- Connecteren
  - Upload het voorbeeldprogramma in de MKR WAN 1300. File -> Examples -> MKR WAN -> LoraSendAndRecieve.
  - Pas in het programma volgende details aan naar je eigen waarden. De waarden kan je vinden op de website van ttn onder je geregistreerde device.
    - devAddr
    - nwkSkey
    - appSkey
  - Hierna zal er op de seriële monitor verschijnen of deze verbinding kan maken.
- Payload formateren
  - Doordat de data die wordt verstuurd over LoRaWan zo klein mogelijk moet zijn is deze gecodeerd. We kunnen instellen hoe deze data gedecodeerd moet worden.
    - Ga naar “End devices” en selecteer het juiste device
    - Ga naar “Payload formatters”
    - Kies bij “Formatter type”: Custom javascript formatter
    - Vul de volgende code in en druk op “save changes”


    - Hierdoor krijg je bij “live data” het volgende:

### Node-red applicatie

- Om onze data te visualiseren/zenden gaan we gebruik maken van node-red met een mqtt server. Het installeren van dit programma kan je via de website van node red doen. Om de applicatie op te starten moet je een cmd openen en “node-red” typen. Hierna zal de applicatie beschikbaar zijn in je browser op het ip “http://127.0.0.1:1880”.
- Data toevoegen in een database
  - Nieuwe data aanmaken als er nog niks bestaat
    - Bij het opstarten van een baken voor de eerste keer, zal er nog geen data bestaan in de database. Bij het opstarten zend de baken altijd een bericht uit waardoor we deze kunnen toevoegen aan de database.
    - In bovenstaande lijn code zal er in de SQL database worden gekeken of er al een id bestaat. Als dit bestaat wordt deze geüpdatet. Ook wordt de huidige tijd geüpdatet. Als er nog geen data bestaan zal er een nieuw worden aangemaakt
  - Data updaten in de database
    - Data wordt gestuurd op een bepaald interval en hierop moet de database ook worden geüpdatet.
    - In bovenstaande lijn code zal er in de SQL database een lijn worden geüpdatet waar het id = id.
  - GPS updaten in de database
    - De locatie zal worden geüpdatet waar het id = id.
- Data ophalen vanuit een database
  - Drop down menu aanmaken uit een database.
    - Doordat we enkel de id’s willen kunnen kiezen van de baken gaan we deze in een list plaatsen.
      - We maken een variabele waarin we alle id’s toevoegen doordat we door de data loopen en elke keer het id eruit halen. Hierna voegen we de id’s toe aan de options key van het msg object.
    - Het drop down menu geeft het gekozen id weer in “msg.payload”. Hiermee kunnen we de aanvullende data uit de database ophalen.
      - We selecteren de correcte rui uit de database waarin het id overeenkomt met het gekozen id.
    - Als we de data uit de database hebben opgehaald kunnen we deze ook printen in het “debug” venster.
      - “msg.payload[0].id”
      - “msg.payload[0].lat”

### Node-red status codes

Om aan te geven of de baken correct werkt en of er verbinding is geweest zullen we gebruik maken van status codes.

Doordat we 3 armaturen hebben kunnen we per situatie een ander getal doorsturen. Maar als we gebruik maken van een binaire code die de armaturen apart voorstellen gaat dit met minder dan één byte. Hierdoor versturen we ook minder data over het LoRaWan netwerk.

- 4 bits: 0000
  - De eerste 3 bits gebruiken we om de status van de lampen door te geven
    - Als één van deze bits hoog is dan wilt dit zeggen dat dit armatuur niet aan is.
  - De laatste bit gebruiken we om aan te geven of er al een controle is uitgevoerd of niet.
    - Als dit 0 is dan is er nog geen controle uitgevoerd
    - Als dit 1 is dan is er een controle uitgevoerd
  - Voorbeeld:
    - 0000 = Er is nog geen controle uitgevoerd op de baken
    - 1001 = De eerste lamp brandt niet en er is een controle uitgevoerd
- Node-red
  - We krijgen via LoRaWan nog steeds een int doorgestuurd. Deze kunnen we omzetten naar een binair getal waaruit we onze data kunnen halen

Node-red status

### Data µC -> Node-red

- Data versturen vanaf de microcontroller naar de node-red applicatie. De data die wordt ontvangen zal hiervoor moeten worden doorgestuurd worden naar de node-red applicatie. Dit gebeurd via een mqtt server, om deze in te stellen moet je de juiste server configureren in het mqtt blok. Als dit correct gebeurd is zal er “connected” staan onderaan de blok.


- Schema verduidelijking
  - De paarse blok is de ontvangen “mqtt in”
  - De groene blokken laten data zien in het “debug” venster
  - De gele blok zet data om naar een JavaScript Object als dit het geval nog niet was
  - De licht gele blok kan functies uitvoeren. Deze gebruiken we om de data te filteren

### Data Node red -> µC

- Data versturen vanaf node-red naar de microcontroller.
- Schema verduidelijking
  - De paarse blok is de zender “mqtt out”
  - De groene blok laat data zien in het “debug” venster
  - De gele blok zet data om naar een downlink Object
  - De blauwe knoppen zijn knoppen waarop gedrukt kan worden om een actie uit te voeren.

### Node red dashboard

- Installeren
  - Om gebruik te kunnen maken van het node-red dashboard moeten we deze extensie installeren. Dit doen we door in de command prompt het volgende te typen. “npm install node-red dashboard” Hierna kunnen we gebruik maken van alle opties die in deze extensie zitten.
- Input
  - Om acties uit te voeren kunnen we gebruik maken van verschillende input mogelijk heden. In onze toepassing maken we gebruik van een button en de dropdown.
  - Aan de ingang van een button kan je data meegeven door het msg object hieraan te koppelen.
- Output
  - De data dat we terug krijgen vanaf de baken gaan we weergeven met behulp van tekst. In het veld “value format” kunnen we de waarden dat we willen tonen toevoegen.
- Dashboard resultaat
  - Het dashboard is te vinden op volgende link. “http://127.0.0.1:1880/ui”


    - In de dropdown kan je selecteren welke baken je graag zou willen bedienen/uitlezen.
    - Lamp1, Lamp2 en Lamp3 geven de status aan van de lampen. Als er een 0 staat wilt dit zeggen dat die lamp uit is. Als er een 1 staat wilt dat zeggen dat de lamp aan is.
    - Last updated geeft aan wanneer de laatste communicatie is gebeurd tussen de database en de baken.
    - Bat voltage is de spanning van de batterij.
    - Status geeft aan wat er met de baken aan de hand is.
    - Baken aan, Baken uit en Baken automatisch zijn 3 knoppen die elk de corresponderende actie uitvoeren.
    - Capaciteit is op basis van de bat voltage bereken in watt uur.

## Programma

- Node-red


  - Link: https://github.com/LaheyKevin/Slimme_Baken_PoAB/tree/main/LoRaWan/Node-red
- Arduino
  - Link: https://github.com/LaheyKevin/Slimme_Baken_PoAB/tree/main/LoRaWan/Programma_Kast

# Volgende iteratie

In dit gedeelte gaan we bespreken wat er in de volgende iteratie aangepast zou moeten worden en waarom.

- Keuze tussen mosfet of Led driver.
  - Op de huidige PCB is de uitgang van de MKR WAN 1300 verbonden met de mosfet. Deze mosfet schakelt de 5V voor de EN pin van de led driver. In de volgende iteratie gaan we één van deze componenten niet meer nodig hebben omdat er dan een armatuur afgeleverd zal worden.
  - De mosfet zal aanwezig blijven als de armaturen enkel 12V nodig hebben en deze een interne led driver gebruiken.
  - De led driver zal aanwezig blijven als de armaturen geen led driver aanwezig hebben.
- Integratie van de INA219
  - Op de huidige PCB zit een spanning deler met 2 weerstanden die direct na de 12V wordt gemeten. Het probleem hiermee is dat, in een latere versie het systeem gevoegd zal worden door een solar charger waardoor er een stabiele 12V zal binnen komen en het zou lijken dat de batterij altijd volledig is opgeladen. We moeten dus een extra connectie voorzien tussen de solar charger en de batterij om te kunnen meten welke spanning hierover staat. En eventueel welke stroom de schakeling verbruikt.
- Meerdere bakens tegelijktijdig aansturen vanop 1 platform
  - In het huidige programma is het enkel mogelijk om één baken te selecteren en deze aan te doen. Volgende iteratie zouden we graag een lijst van bakens ineens aan/uit schakelen.
- LoRaWan acties
  - In het huidige prototype zal de microcontroller enkel een bericht sturen nadat deze een actie heeft uitgevoerd. Hierdoor kan het zijn dat de baken stuk gaat nadat deze al drie uur aanstaat en hierdoor geen foutmelding genereert.
  - Als we de GPS module kunnen gebruiken om de tijd op te halen kunnen we om de x aantal minuten de controle op de armaturen uitvoeren. Het nadeel hiervan is dat als je een baken hebt aangezet dat je hier niet direct reactie van terug zou krijgen.
- PCB update
  - De pcb zal opnieuw moeten worden en rekeningen gehouden met volgende zaken.
    - Testpinnen
    - Verticale connectoren
    - Correcte connectoren voor bepaalde stromen
    - INA219 integratie
    - 12V voeding reguleren naar 5V via een IC

# Bronvermelding

arduino. (z.d.). MKR WAN 1300. Opgehaald van arduino.cc: https://docs.arduino.cc/hardware/mkr-wan-1300

evaherrada. (2023, 5 12). Adafruit_INA219. Opgehaald van github: https://github.com/adafruit/Adafruit_INA219

mikalhart. (2022, 9 20). TinyGPSPlus. Opgehaald van github: https://github.com/mikalhart/TinyGPSPlus

nodered. (2023, 5 26). nodered. Opgehaald van nodered: https://flows.nodered.org/node/node-red-dashboard

nodered. (z.d.). Running Node-RED locally. Opgehaald van nodered: https://nodered.org/docs/getting-started/local

Olayinka, B. (2021, 6 10). The Things Stack Documentation. Opgehaald van thethingsindustries: https://www.thethingsindustries.com/docs/

RobTillaart. (2023, 3 31). ADS1X15. Opgehaald van github: https://github.com/RobTillaart/ADS1X15

Selimović, N. (2021, 6 10). Node-RED. Opgehaald van thethingsindustries: https://www.thethingsindustries.com/docs/integrations/node-red/

thethingsnetwork. (z.d.). Device Classes. Opgehaald van thethingsnetwork: https://www.thethingsnetwork.org/docs/lorawan/classes/

thethingsnetwork. (z.d.). thethingsnetwork. Opgehaald van thethingsnetwork: https://www.thethingsnetwork.org/

TTN Mapper. (z.d.). TTN Mapper. Opgehaald van TTN Mapper: https://ttnmapper.org/heatmap/

wikipedia. (2021, 6 10). Halfgeleiderrelais. Opgehaald van wikipedia: https://nl.wikipedia.org/wiki/Halfgeleiderrelais

wikipedia. (2023, 1 10). MOSFET. Opgehaald van wikipedia: https://nl.wikipedia.org/wiki/MOSFET

wikipedia. (2023, 3 26). Relais. Opgehaald van wikipedia: https://nl.wikipedia.org/wiki/Relais

2 Documentatie: Slimme bakenverlichting PoAB

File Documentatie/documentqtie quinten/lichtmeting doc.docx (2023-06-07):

Buiten een stroommeting moet er ook nog een andere controle vorm zijn om te zien of de leds branden, dit gaat waarschijnlijk hardware matig moete gebeuren, je hebt hier dan een aantal mogelijkheden om dit te doen, je kunt een fotodiode, een fototransistor, fotometer en zelfs een luxmeter gebruiken.

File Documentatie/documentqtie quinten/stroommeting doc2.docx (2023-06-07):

TEMT6000X01 x4 20mA x 6V

AQY211EHAZ x3 1A x 5V

ACS712ELCTR-05B-T x3 13mA x 5V

INA219 10mA x 5V

L7805CV 6mA x 5V

Lampen x3 2A x 12V

ADS1115 10mA x 5V

NEO-7M 67mA x 5V

BCR411UW6-7 x3 150mA x 5V

totaal = 9662mA

9662 * 24h = 231.888mAh = 231,888Ah / 3 = 77.3Ah

Er kan theoretisch maximum 9,662A door het bordje vloeien, als je dit 24 uur wilt laten branden heb je een batterij van 231,888Ah of drie batterijen van 77,3Ah. De kans dat er 9,662A door het bordje vloeit is vrij klein, dus moet je niet naar een batterij zoeken die voor 24 uur lang deze stroom aan kan.

Het is handig dat je een batterij zoekt die zoveel mogelijk ampère-uur levert en in de behuizing past, want je wilt een batterij hebben die zo lang mogelijk meegaat. AGM batterijen zijn het beste soort batterijen voor op te laden, dus heb ik gezocht naar AGM batterijen, ik heb er 1 gevonden die 12V levert en 50Ah.

Links naar informatie over de batterijen:

- https://www.bynomads.nl/camper-bouwen/camper-accu/
- https://www.intercel.eu/nl/veelgestelde-vragen/wat-is-een-agm-accu/
- https://www.zwiebelfam.nl/lood-gel-agm-of-lifepo4/

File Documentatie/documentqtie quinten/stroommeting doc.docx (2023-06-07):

TEMT6000X01 x4 20mA x 6V

AQY211EHAZ x3 1A x 5V

ACS712ELCTR-05B-T x3 13mA x 5V

INA219 10mA x 5V

L7805CV 6mA x 5V

Lampen x3 2A x 12V

ADS1115 10mA x 5V

NEO-7M 67mA x 5V

BCR411UW6-7 x3 150mA x 5V

totaal = 9662mA

3545 * 24h = 85.080mAh = 85Ah / 3 = 28.4Ah

Voor onze leds minstens 24 uur te laten branden, hebben we minstens een batterij nodig met 85,1Ah of drie van 28.4Ah, de lichtbakens gebruiken nu drie batterijen met 26Ah, wat voldoende is voor 22 uur te laten branden, we kunnen deze misschien blijven gebruiken of we gebruiken, een iets kleinere batterij met de zelfde Ah, of een andere batterij die 30Ah levert maar geen 6V, waardoor we de spanning moeten reguleren met een component.

Link naar batterij met 6V, 26Ah:

https://www.batteryspace.com/nimh-battery-pack-6v-26ah-156wh-40a-rate-5xm.aspx

Link naar andere batterij met 15.6V, 30Ah:

Custom NiMH Battery Pack: 15.6V 30Ah (468Wh, 30A rate, MH-D30) (batteryspace.com) (https://www.batteryspace.com/custom-nimh-battery-pack-15-6v-30ah-468wh-30a-rate-mh-d30.aspx)

Link naar andere batterij met 3.6V, 30Ah:

NiMH Battery Pack: 3.6V 30Ah (108Wh, 9xD, 3x3S/S) (batteryspace.com) (https://www.batteryspace.com/nimh-battery-pack-3-6v-30ah-108wh-9xd-3x3s-s.aspx)

AGM batterijen zijn beter voor op te laden, dus heb ik gezocht naar AGM batterijen, ik heb er 1 gevonden die 12V levert en 65Ah, maar deze past niet waardoor deze niet kan, .

Links naar informatie over de batterijen:

- https://www.bynomads.nl/camper-bouwen/camper-accu/
- https://www.intercel.eu/nl/veelgestelde-vragen/wat-is-een-agm-accu/
- https://www.zwiebelfam.nl/lood-gel-agm-of-lifepo4/

link naar de website van de batterij:

https://www.accuserviceholland.nl/soorten-accus/agm-semi-tractie-accus/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

Link naar batterij met 12V, 65Ah:

https://www.accuserviceholland.nl/deep-cycle-agm-accu-12-volt-65-ah.html

https://accu4all.nl/shop/multipower-mp50-12c-mpc-loodaccu-agm-12volt-50ah/

https://www.accuserviceholland.nl/2-stuks-accu-agm-ev12050-12-volt-50-ampere.html

https://www.123accu.nl/Landport-EV12-50-EV12050-AGM-Deep-Cycle-accu-12V-50-Ah-T6-terminal-i43144.html

Voor de baterijen te voeden hebben we zonnepanelen nodig die 6V en minstens 18.5W leveren, ik heb een zonnepaneel gevonden, die genoeg watt en de juiste voltage levert, deze levert 20W levert.

Link naar zonnepaneel 6V, 20W:

https://www.kiwi-electronics.com/nl/zonnepanelen-en-opladers-168/20-watt-6-volt-zonnepaneel-etfe-10925

Om de data uit de stroomsensor naar de MKR WAN 1300 te sturen was er een probleem, het bordje stuurde namelijk een analoog signaal tussen de 0 en 5V, en de analoge pinnen van de MKR mogen maar maximum 3.3V binnenkrijgen. Hier is er een oplossing voor gevonden, we gaan namelijk een ADC I2C bordje gebruiken, deze zet de analoge waarde om naar een digitale en deze wordt dan via I2C gestuurd naar het bordje, waardoor het spanningsverschil probleem word opgelost.

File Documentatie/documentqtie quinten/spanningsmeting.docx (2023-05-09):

De spanningsmeting gaan we doen met een INA219B, ik heb hier werkende code voor gevonden, ik heb er ook voor gezorgd dat er in deze code de capaciteit van een batterij berekent. Dit wordt gedaan met deze formule: Vaccu * Ah.

Dit is de code:

#include <Wire.h>

#include <Adafruit_INA219.h>

Adafruit_INA219 ina219;

void setup(void)

{

Serial.begin(115200);

while (!Serial) {

// will pause Zero, Leonardo, etc until serial console opens

delay(1);

}

Serial.println("Hello!");

// Initialize the INA219.

// By default the initialization will use the largest range (32V, 2A). However

// you can call a setCalibration function to change this range (see comments).

if (! ina219.begin()) {

Serial.println("Failed to find INA219 chip");

while (1) { delay(10); }

}

// To use a slightly lower 32V, 1A range (higher precision on amps):

//ina219.setCalibration_32V_1A();

// Or to use a lower 16V, 400mA range (higher precision on volts and amps):

//ina219.setCalibration_16V_400mA();

Serial.println("Measuring voltage and current with INA219 ...");

}

void loop(void)

{

float shuntvoltage = 0;

float busvoltage = 0;

float current_mA = 0;

float loadvoltage = 0;

float power_mW = 0;

float capacity = 0;

float batAh = 0.20;

shuntvoltage = ina219.getShuntVoltage_mV();

busvoltage = ina219.getBusVoltage_V();

current_mA = ina219.getCurrent_mA();

power_mW = ina219.getPower_mW();

loadvoltage = busvoltage + (shuntvoltage / 1000);

Serial.print("Bus Voltage: "); Serial.print(busvoltage); Serial.println(" V");

Serial.print("Shunt Voltage: "); Serial.print(shuntvoltage); Serial.println(" mV");

Serial.print("Load Voltage: "); Serial.print(loadvoltage); Serial.println(" V");

Serial.print("Current: "); Serial.print(current_mA); Serial.println(" mA");

Serial.print("Power: "); Serial.print(power_mW); Serial.println(" mW");

Serial.println("");

capacity = busvoltage * batAh;

Serial.print("Capacity: "); Serial.print(capacity); Serial.println(" Wh");

Serial.println("");

delay(2000);

}

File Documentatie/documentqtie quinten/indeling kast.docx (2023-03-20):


Zonnepanelen =

PCB =

Batterij =

Antenne =

Plakkaten =

Doorzichtige plaat =

De antenne gaat wel aan de buitenkant zijn.

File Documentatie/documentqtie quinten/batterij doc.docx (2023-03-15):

Voor onze leds minstens 24 uur te laten branden, hebben we minstens een batterij nodig met 6Ah, de lichtbakens gebruiken nu een batterij met 26Ah, wat meer als voldoende is, we kunde deze misschien blijven gebruiken of we gebruiken, een iets kleinere batterij met de zelfde Ah of een batterij die kleiner is en maar 9.6Ah heeft.

https://www.mister-battery.be/nl/lifepo4-batterij-6v/1206-batterie-lifepo4-6v-98ah-b06010.html

https://www.batteryspace.com/nimh-battery-pack-6v-26ah-156wh-40a-rate-5xm.aspx

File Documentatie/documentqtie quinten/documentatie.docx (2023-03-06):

Ik heb de gps werkende gekregen, hiervoor moest ik mijn bordje buiten zetten en verbinden met de 5V in plaats van de 3.3V, ik heb ook hardware serial moeten gebruiken in plaats van de softwareserial.

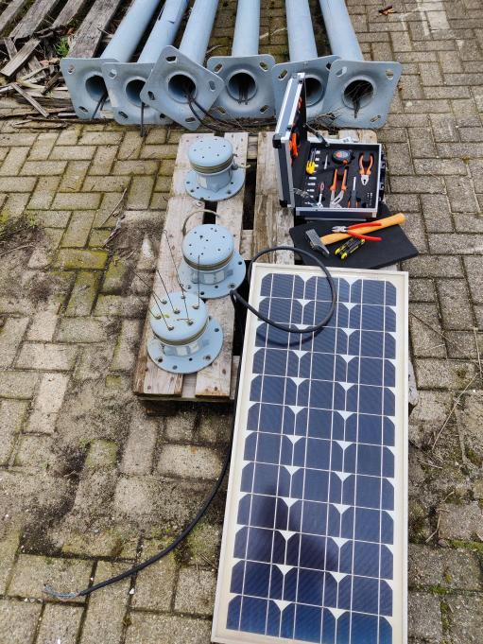
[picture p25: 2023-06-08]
Fotos/Ophaling1.jpg

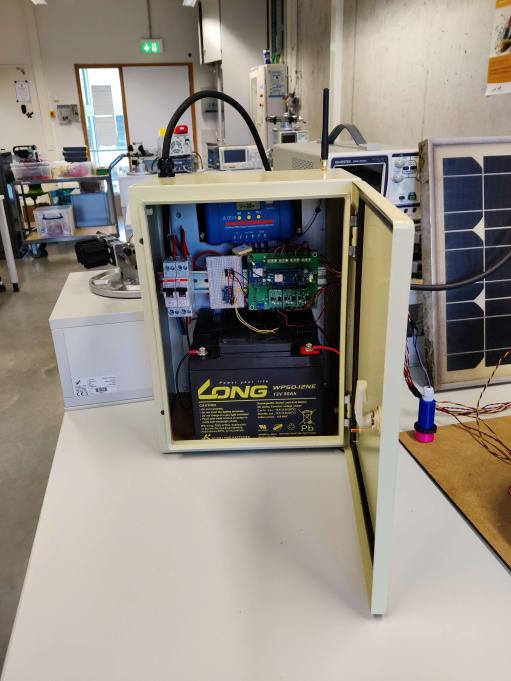
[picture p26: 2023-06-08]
Fotos/Opstelling3.jpg

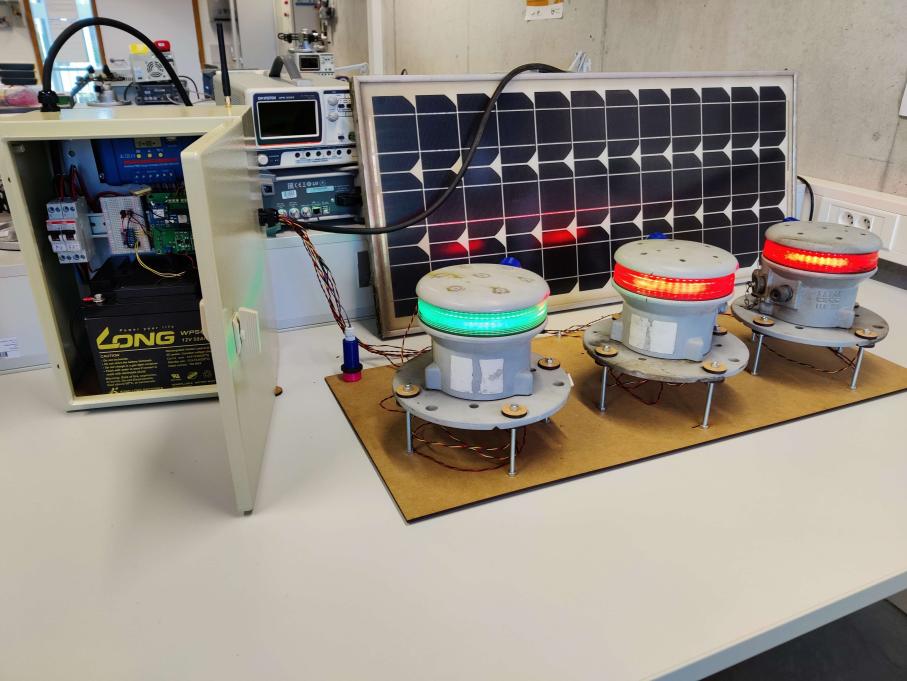
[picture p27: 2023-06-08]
Fotos/Opstelling2.jpg

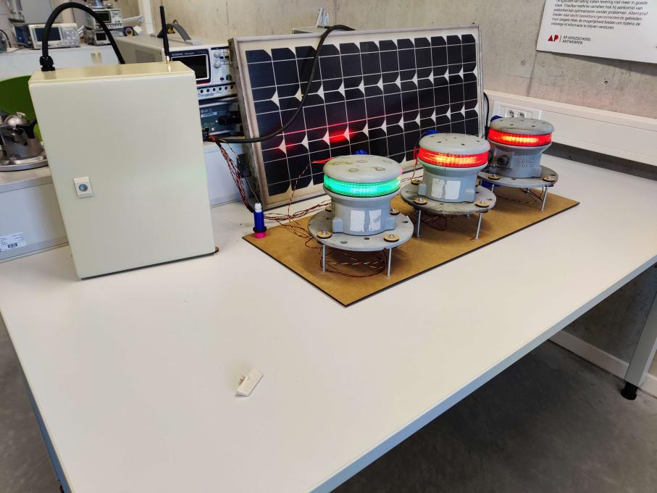
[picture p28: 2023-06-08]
Fotos/Opstelling1.jpg

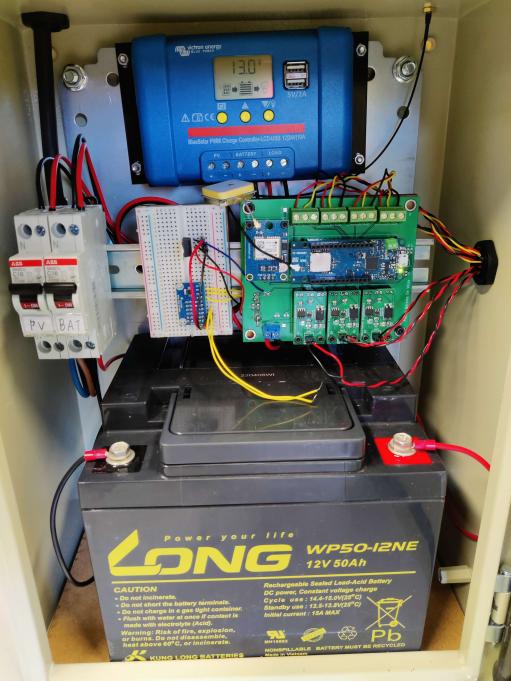
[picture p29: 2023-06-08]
Fotos/Opstelling4.jpg

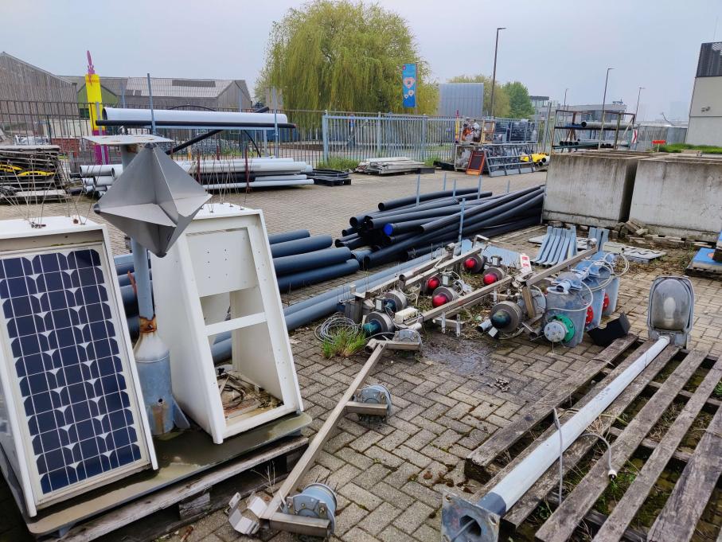
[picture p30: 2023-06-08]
Fotos/Ophaling2.jpg

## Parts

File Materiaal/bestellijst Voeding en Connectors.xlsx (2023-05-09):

Winkel | Article Nr | Description | Amount | Item Price | Total | inc. Tax | URL
farnell | 3184Y-0.75MMBLK | Multicore Cable, Flexible, Per M, Unscreened, 4 Core, 0.75 mm² | 10 | €2.110 | €21.100 | €25.531 | https://be.farnell.com/pro-power/3184y-0-75mmblk/cable-flex-3184y-black-0-75-per/dp/1387692
farnell | 3183Y-2.50MMBLK | Multicore Cable, Flexible, Per M, Unscreened, 3 Core, 2.5 mm² | 10 | €3.560 | €35.600 | €43.076 | https://be.farnell.com/pro-power/3183y-2-50mmblk/cable-flex-3183y-black-2-5mm-per/dp/1387690
RS components | 793-4427 | RF Solutions Male SMA to Female SMA Coaxial Cable, RG58, 5m | 1 | €17.710 | €17.710 | €21.429 | https://benl.rs-online.com/web/p/coaxial-cable/7934427
tinytronics | 1102 | GPS Antenne met SMA connector - 3m - Incl. SMA naar uFL adapter | 1 | €5.500 | €5.500 | €6.655 | https://www.tinytronics.nl/shop/nl/communicatie-en-signalen/draadloos/antennes/gps/gps-antenne-met-sma-connector-3m-incl.-sma-naar-ufl-adapter
farnell | MG-20 BLACK | M20 IP68 Nylon Cable Gland Black - Single Pack | 10 | €0.383 | €3.830 | €4.634 | https://be.farnell.com/pro-power/mg-20-black/m20-cable-gland-black/dp/3498404?st=cable%20gland%20black
RS components | 899-0917 | Altech Steel Perforated DIN Rail, Top Hat Compatible, 1m x 35mm x 7.5mm | 1 | €3.480 | €3.480 | €4.211 | https://benl.rs-online.com/web/p/din-rails/8990917
RS components | 768-4611 | Weidmuller Black W Fused DIN Rail Terminal, Single level, 4mm², 300 V | 2 | €2.270 | €4.540 | €5.493 | https://benl.rs-online.com/web/p/din-rail-terminal-blocks/7684611
RS components | 178-8327 | RS PRO Red Insulated Female Spade Connector, Receptacle, 0.5 x 4.75mm Tab Size, 0.5mm² to 1.5mm² | 100 | €0.048 | €4.800 | €5.808 | https://benl.rs-online.com/web/p/spade-connectors/1788327
RS components | 178-8674 | RS PRO Insulated Ring Terminal, 4.3mm Stud Size, 0.5mm² to 1.5mm² Wire Size, Red | 100 | €0.042 | €4.200 | €5.082 | https://benl.rs-online.com/web/p/ring-terminals/1788674
RS components | 178-7293 | RS PRO Insulated Crimp Bootlace Ferrule, 8mm Pin Length, 1.5mm Pin Diameter, 0.75mm² Wire Size, Blue | 100 | €0.026 | €2.600 | €3.146 | https://benl.rs-online.com/web/p/bootlace-ferrules/1787293
RS components | 178-8743 | RS PRO Insulated Crimp Bootlace Ferrule, 10mm Pin Length, 3.3mm Pin Diameter, 2 x 2.5mm² Wire Size, Grey | 100 | €0.059 | €5.900 | €7.139 | https://benl.rs-online.com/web/p/bootlace-ferrules/1788743
RS components | 178-8715 | RS PRO Insulated Crimp Spade Connector, 0.5mm² to 1.5mm², 22AWG to 16AWG, 5.3mm Stud Size Vinyl, Red | 100 | €0.044 | €4.400 | €5.324 | https://benl.rs-online.com/web/p/fork-terminals/1788715
RS components | 613-9463 | RS PRO Insulated Crimp Spade Connector, 0.5mm² to 1.5mm², 22AWG to 16AWG, M6 Stud Size Vinyl, Red | 100 | €0.127 | €12.700 | €15.367 | https://benl.rs-online.com/web/p/fork-terminals/6139463
RS components | 534-531 | RS PRO Yellow Insulated Female Spade Connector, Receptacle, 6.3 x 0.8mm Tab Size, 2.5mm² to 6mm² | 100 | €0.234 | €23.400 | €28.314 | https://benl.rs-online.com/web/p/spade-connectors/0534531
conrad | 2497145 - 62 | Victron Energy Blue-Solar PWM-LCD&USB Solar laadregelaar PWM 12 V, 24 V 10 A | 1 | €71.990 | €71.990 | €87.108 | Victron Energy Blue-Solar PWM-LCD&USB Solar laadregelaar PWM 12 V, 24 V 10 A kopen ? Conrad Electronic (https://www.conrad.be/nl/p/victron-energy-blue-solar-pwm-lcd-usb-solar-laadregelaar-pwm-12-v-24-v-10-a-2497145.html)
conrad | 630860 - 62 | CTEK Druppellader MXS 5.0 12 V 0.8 A, 5 A | 1 | €109.990 | €109.990 | €133.088 | https://www.conrad.be/nl/p/ctek-druppellader-mxs-5-0-12-v-0-8-a-5-a-630860.html
conrad | 2368959 - 62 | Long WP50-12NE Loodaccu 12 V 50 Ah Loodvlies (AGM) (b x h x d) 199 x 171 x 166 mm M6-schroefaansluiting Cyclusbestendig, | 1 | €169.990 | €169.990 | €205.688 | Long WP50-12NE Loodaccu 12 V 50 Ah Loodvlies (AGM) (b x h x d) 199 x 171 x 166 mm M6-schroefaansluiting Cyclusbestendig, kopen ? Conrad Electronic (https://www.conrad.be/nl/p/long-wp50-12ne-loodaccu-12-v-50-ah-loodvlies-agm-b-x-h-x-d-199-x-171-x-166-mm-m6-schroefaansluiting-cyclusbestendig-2368959.html)
RS components | 238-4811 | Legrand Fuse Switch Disconnector, SP + N Pole, 10A Max Current | 1 | €21.100 | €21.100 | €25.531 | https://benl.rs-online.com/web/p/fuse-switch-disconnectors/2384811
RS components | 783-3383 | SIBA 10A F Glass Cartridge Fuse, 6.3 x 32mm | 4 | €0.476 | €1.904 | €2.304 | https://benl.rs-online.com/web/p/cartridge-fuses/7833383
 |  |  |  | totaal: | €522.830 | €632.624

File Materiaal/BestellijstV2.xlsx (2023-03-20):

Winkel | Artikel Nr | Description | Amount | Price | Total | Inc. Tax | URL | Remarks | Remarks2
Digi-Key Electronics | TEMT6000X01 | Light intensity sensor | 10 | €1.31 | €13.10 | 15.85 € | https://www.digikey.be/nl/products/detail/vishay-semiconductor-opto-division/TEMT6000X01/1681189 |  | https://www.tinytronics.nl/shop/en/sensors/optical/light-and-color/temt6000-light-sensor-module
Farnell | AQY211EHAZ | Mosfet Relay, 1A, 30V DIP-4 | 8 | €3.44 | €27.52 | 33.30 € | https://be.farnell.com/panasonic/aqy211ehaz/mosfet-relay-spst-1a-30v-dip-4/dp/3881433
Digi-Key Electronics | 620-1189-1-ND - Cut Tape | Linear Current sensor | 8 | €3.54 | €28.35 | 34.31 € | https://www.digikey.be/nl/products/detail/allegro-microsystems/ACS712ELCTR-05B-T/1284593 | https://www.youtube.com/watch?v=DVp9k3xu9IQ | https://www.tinytronics.nl/shop/nl/sensoren/stroom-spanning/acs712-stroomsensor-module-5a
tinytronics | INA219B | INA219 I2C DC Stroom- en spanningsmeter 3.2A | 4 | €4.13 | €16.52 | 19.99 € | https://www.tinytronics.nl/shop/nl/sensoren/stroom-spanning/ina219-i2c-dc-stroom-en-spanningsmeter-3.2a-module
Farnell | SG18B104K500CT | SMD Ceramic Capacitor 0,1µF | 10 | €0.28 | €2.83 | 3.42 € | https://be.farnell.com/walsin/sg18b104k500ct/cap-0-1uf-50v-mlcc-0603/dp/3764215
Farnell | CC0603KRX7R9BB102 | SMD Ceramic Capacitor 1000pF | 10 | €0.19 | €1.88 | 2.27 € | https://be.farnell.com/yageo/cc0603krx7r9bb102/cap-1000pf-50v-10-x7r-0603/dp/722170?st=1nf
Digi-Key Electronics | L7805CV | L7805CV, IC REG 5V 1,5A | 4 | €0.65 | €2.60 | 3.15 € | https://www.digikey.be/nl/products/detail/stmicroelectronics/L7805CV/585964 | Alternatief: https://www.digikey.be/nl/products/detail/nisshinbo-micro-devices-inc/RP132S501D-E2-FE/10216742
tinytronics | TEMT6000MOD | Light intensity sensor | 2 | €3.00 | €6.00 | 7.26 € | https://www.tinytronics.nl/shop/en/sensors/optical/light-and-color/temt6000-light-sensor-module
 |  |  |  |  | €0.00 | 0.00 €
tinytronics | ACS712-5A | Linear Current sensor module | 2 | €3.50 | €7.00 | 8.47 € | https://www.tinytronics.nl/shop/nl/sensoren/stroom-spanning/acs712-stroomsensor-module-5a
 |  |  |  |  | €0.00 | 0.00 €
 |  |  |  |  | €0.00 | 0.00 €
 |  |  |  |  | €0.00 | 0.00 €
 |  |  |  |  | €0.00 | 0.00 €
 |  |  |  |  | €0.00 | 0.00 €
 |  |  |  |  | €0.00 | 0.00 €

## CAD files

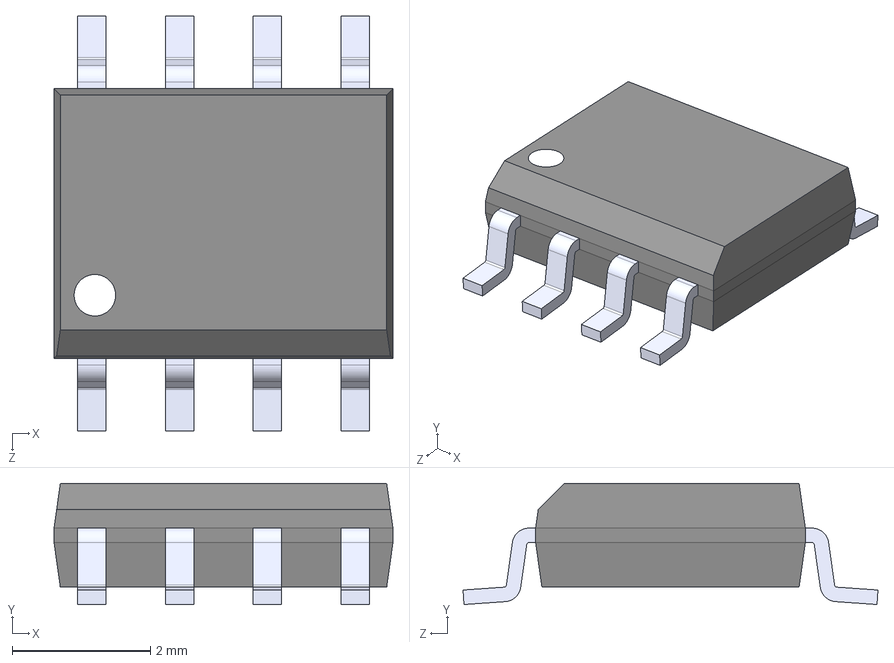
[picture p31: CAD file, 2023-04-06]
PCB/Moons_Quinten_PCB/printplaat2/pcb_PoAB/ACS712ELCTR-05B-T/ACS712ELCTR-05B-T.step
4.90 x 1.75 x 6.00 mm

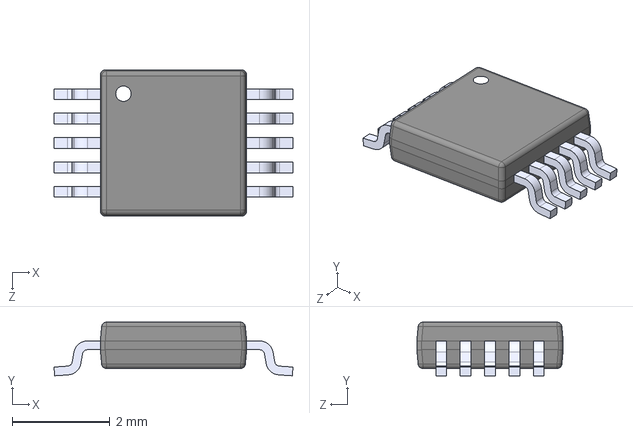
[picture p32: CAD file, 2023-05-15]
PCB/Moons_Quinten_PCB/printplaat2/pcb_PoAB/ADS1115/ADS1115.step
4.90 x 1.10 x 3.00 mm

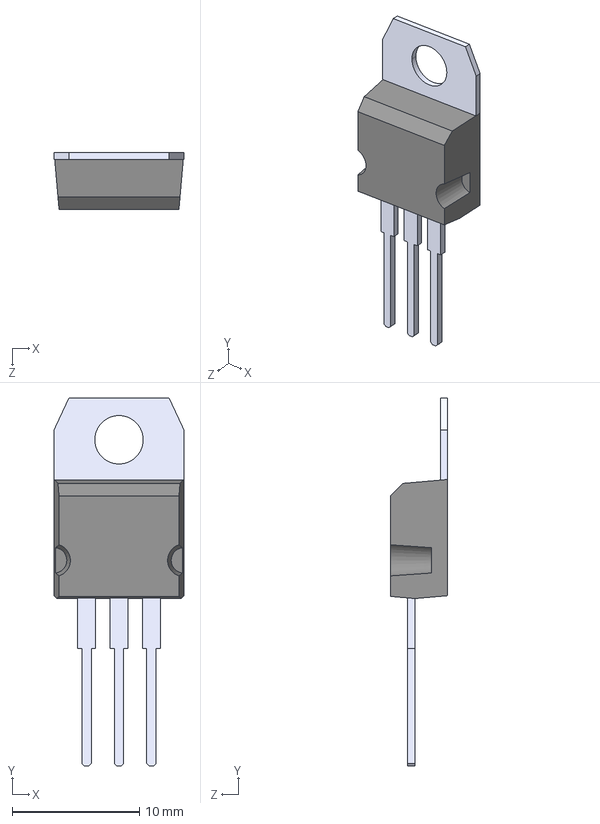
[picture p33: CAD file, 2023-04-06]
PCB/Moons_Quinten_PCB/printplaat2/pcb_PoAB/L7805CV/L7805CV.step
10.2 x 28.9 x 4.50 mm

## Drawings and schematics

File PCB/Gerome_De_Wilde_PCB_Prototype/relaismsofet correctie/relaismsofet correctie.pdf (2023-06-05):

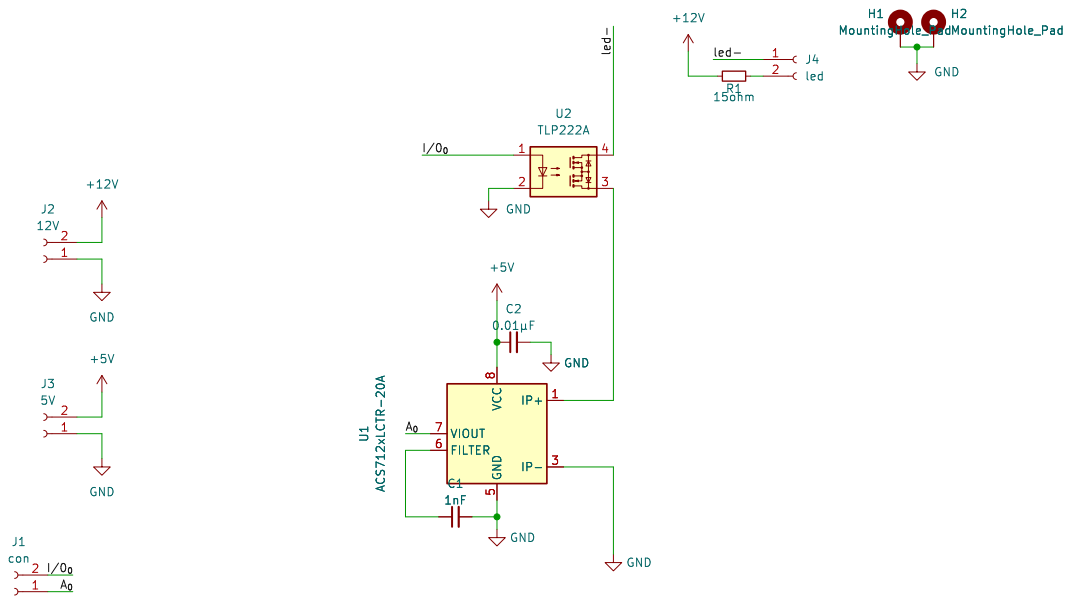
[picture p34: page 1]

Id: 1/1 Title: File: relaismosfet.kicad_sch Sheet: / GND

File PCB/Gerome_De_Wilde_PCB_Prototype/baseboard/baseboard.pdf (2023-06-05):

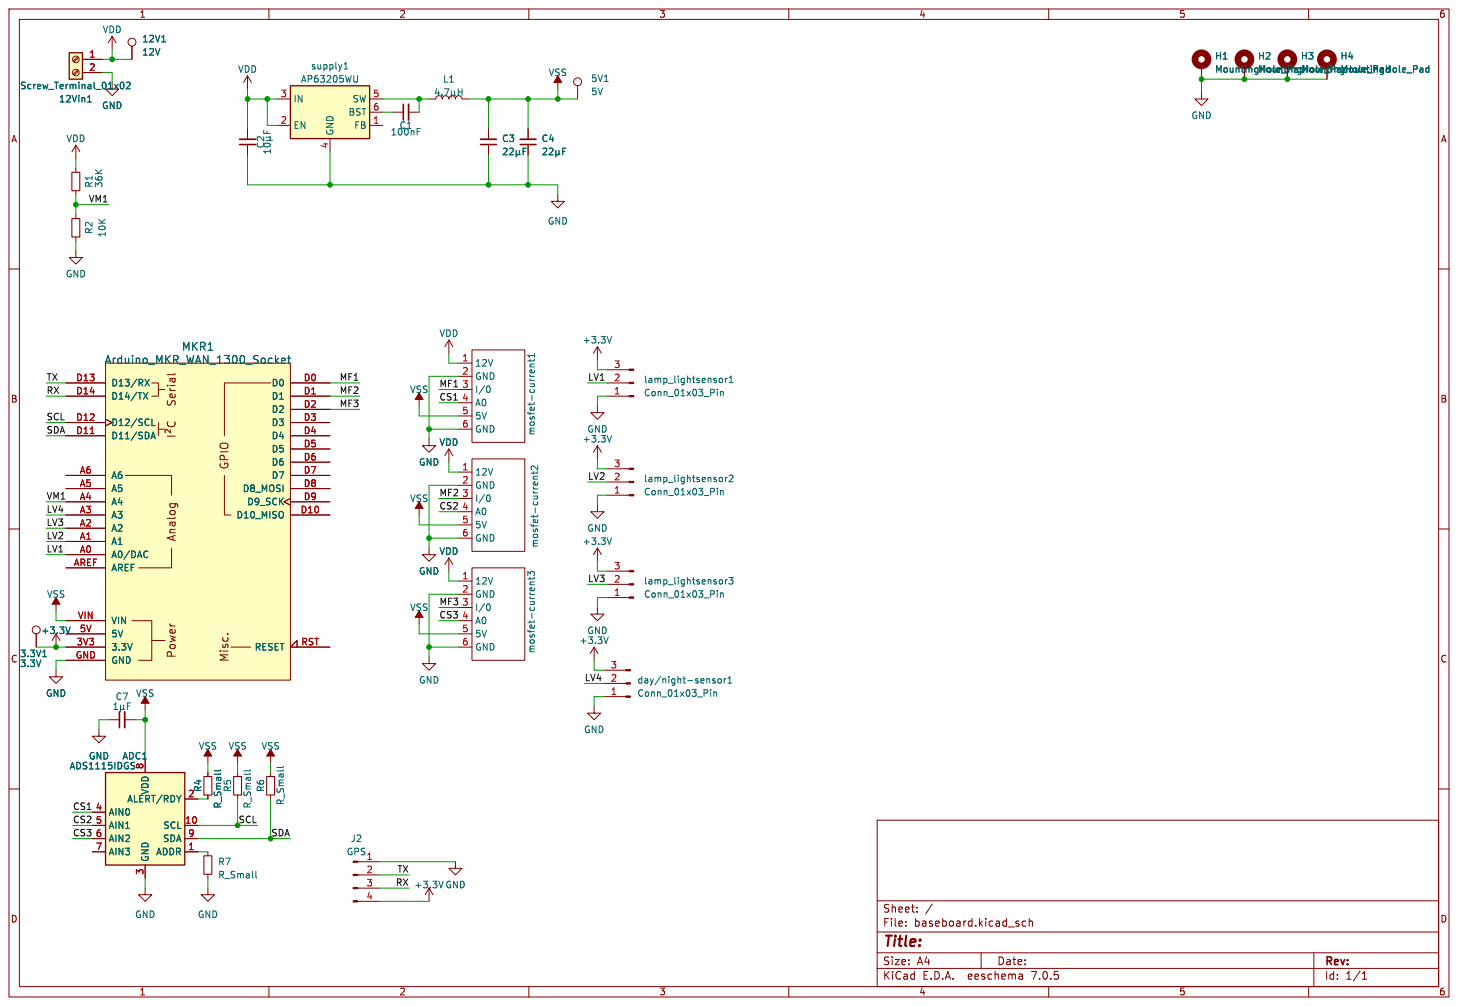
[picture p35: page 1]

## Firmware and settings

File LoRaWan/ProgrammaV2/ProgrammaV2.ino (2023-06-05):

//Kevin Lahey
//IoT project
//Slimme baken PoAB

//Librarys
#include <MKRWAN.h> //MKR WAN
#include "arduino_secrets.h"  //File for configuration
#include <TinyGPSPlus.h>  //GPS library
#include <Adafruit_INA219.h>  //Voltage/current board
#include <ADS1X15.h>  //I2C ADC for current board

//Variables
unsigned int AmbientLight;  //Main light
unsigned int LDR1;  //Led1
unsigned int LDR2;  //Led2
unsigned int LDR3;  //Led3

unsigned int MeasureLDR1[3];
unsigned int MeasureLDR2[3];
unsigned int MeasureCurrent1[3];
unsigned int MeasureCurrent2[3];
char lights[] = "0:0:0:";
char statusCode[] = "0000";

int ambientLightDark = 750; //When baken needs to turn on

bool lightsStatus = false;
bool automaticMode = true;
bool gotGPS = false;

//Objects
LoRaModem modem;
TinyGPSPlus gps;
Adafruit_INA219 ina219;
ADS1115 ADS(0x48);  //I2C addres 0x48 for current board

void setup() {
  Serial.begin(115200);
  Serial1.begin(9600);  //GPS serial 13RX,14TX
  Serial.println("Serial gestard");

  //Inputs LDR's
  pinMode(A0, INPUT); //Ambient Light
  pinMode(A1, INPUT); //Led1
  pinMode(A2, INPUT); //Led2
  pinMode(A3, INPUT); //Led3

  //Output Led's
  pinMode(0, OUTPUT); //SSR1
  pinMode(1, OUTPUT); //SSR2
  pinMode(2, OUTPUT); //SSR3
  pinMode(6, OUTPUT); //BUILD IN LED

  //INA219 Voltage/Current board
  if (! ina219.begin()) {
    Serial.println("Failed to find INA219 chip");
  }

  ADS.begin();  //I2C board for current sensor

  //LoRaWan
  if (!modem.begin(EU868)) {
    Serial.println("Failed to start module");
    digitalWrite(6, HIGH);
    while (1) {}
  };
  Serial.println("Module gestart");
  modem.configureClass(CLASS_C);

  int connected = modem.joinOTAA(SECRET_APP_EUI, SECRET_APP_KEY);
  if (!connected) {
    Serial.println("FOUT, geen verbinding, start opnieuw op");
    digitalWrite(6, HIGH);
    while (1) {}
  }
  modem.minPollInterval(60);

  //delay(5000);

  sendLoRaMessage("0:0");
}

//Main program
void loop() {
  //Check ambient light
  AmbientLight = GetLDRValue(A0);

  if (AmbientLight < ambientLightDark && !lightsStatus && automaticMode) { //If darker then value and leds are off
    changeLightState(true);
    Serial.println("Sensor licht aan");
  } else if (AmbientLight > ambientLightDark && lightsStatus && automaticMode) {// If brighter then value and leds are on
    changeLightState(false);
    Serial.println("Sensor licht uit");
  }

  //LoRaWan
  if (modem.available()) {
    char rcv[64] = "";
    int i = 0;
    while (modem.available()) {
      rcv[i % 64] = (char)modem.read();
      ++i;
    }
    String message = rcv;
    Serial.println(message);

    if (message == "L1") {  //LAMP on
      automaticMode = false;
      changeLightState(true);
    } else if (message == "L0") { //LAMP off
      automaticMode = false;
      changeLightState(false);
    } else if (message == "LA") { //Lamp AUTO
      automaticMode = true;
    } else if (message == "GPS" && gotGPS) { //GPS ophalen
      sendLoRaMessage("2:" + String(gps.location.lat()) + ":" + String(gps.location.lng()));
    }
  }

  //GPS
  if (!gotGPS) {
    readGPSData();
  }

  delay(1000);
}

//Functions
void sendLoRaMessage(String data) { //Function to send data over LoRa
  modem.setPort(1);
  modem.beginPacket();
  modem.print(data);
  int err = modem.endPacket(true);
  if (err > 0) {
    Serial.println("Bericht verzonden");
  } else {
    Serial.println("Bericht niet verzonden");
  }
}

unsigned int GetLDRValue(byte pin) { //Function to get LDR value from pin x
  unsigned int valueM = 0;
  for (int i = 0; i < 20; i++) { //mean op 20 measures
    valueM = valueM + analogRead(pin);
  }
  valueM = valueM / 20;
  return valueM;
}

unsigned int GetCurrentValue(int pin) { //Function to get current value from pin x
  unsigned int valueM = 0;
  for (int i = 0; i < 20; i++) { //mean op 20 measures
    valueM = valueM + ADS.readADC(pin);
  }
  valueM = valueM / 20;
  return valueM;
}

void changeLightState(bool state) { //Function to turn on leds
  if (state) {  //Set lights on
    lightsStatus = true;
    checkLightsLDR(MeasureLDR1); //Check value before turning on
    checkLightsCurrent(MeasureCurrent1); //Check value before turing on
    digitalWrite(0, HIGH);
    digitalWrite(1, HIGH);
    digitalWrite(2, HIGH);
    delay(100);
    checkLightsLDR(MeasureLDR2);  //Check value after turning on
    checkLightsCurrent(MeasureCurrent2); //Check value after turing on
    Serial.println(MeasureCurrent1[0]);
    Serial.println(MeasureCurrent2[0]);
    Serial.println(MeasureLDR1[0]);
    Serial.println(MeasureLDR2[0]);
    verifyLightStatus(MeasureLDR1 , MeasureLDR2, MeasureCurrent1, MeasureCurrent2); //Verify if correct

    //Set light status
    if (lights != "1:1:1") {
      statusCode[0] = '1';
    }
  } else {  //Set lights off
    lightsStatus = false;
    digitalWrite(0, LOW);
    digitalWrite(1, LOW);
    digitalWrite(2, LOW);
    checkLightsLDR(MeasureLDR1);  //Check value after turning off
    checkLightsCurrent(MeasureCurrent1); //Check value after turing off

    verifyLightStatus(MeasureLDR1 , MeasureLDR1, MeasureCurrent1, MeasureCurrent1); //Verify if correct

    //Set light status
    if (lights != "0:0:0") {
      statusCode[0] = '1';
    }
  }
  //Send the status of the lights to LoRaWan
  Serial.println(lights);
  sendLoRaMessage("1:" + String(lights) + String(int(ina219.getBusVoltage_V() * 1000)) + ":" + String(statusCode));
}

void checkLightsLDR(unsigned int arr[]) {  //Get LDR value of lights and place in array
  arr[0] = GetLDRValue(A1);
  arr[1] = GetLDRValue(A2);
  arr[2] = GetLDRValue(A3);
}

void checkLightsCurrent(unsigned int arr[]) {  //Get current of lights and place in array
  arr[0] = GetCurrentValue(0);
  arr[1] = GetCurrentValue(1);
  arr[2] = GetCurrentValue(2);
}

void verifyLightStatus(unsigned int a[], unsigned int b[], unsigned int c[], unsigned int d[]) { //To check if the light value changed
  if ((a[0] + 20 < b[0]) && (c[0] < d[0])) { //Check if light is brighter after turn on and there is current flowing
    lights[0] = '1';
  } else {
    lights[0] = '0';
  }
  if ((a[1] + 20 < b[1]) && (c[1] < d[1])) {
    lights[2] = '1';
  } else {
    lights[2] = '0';
  }
  if ((a[2] + 20 < b[2]) && (c[2] < d[2])) {
    lights[3] = '1';
  } else {
    lights[3] = '0';
  }
}

void readGPSData() {
  while (Serial1.available() > 0) {
    if (gps.encode(Serial1.read())) {

      if (gps.location.isValid()) {
        Serial.print(gps.location.lat(), 6);
        Serial.print(gps.location.lng(), 6);
        gotGPS = true;
        break;
      }
    }
  }
}

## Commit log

2023-02-18 add bestellijst
    [BestellijstV1.xlsx, Componenten idee.xlsx]
2023-03-13 add pcb
    [Printplaat.kicad_pcb, Printplaat.kicad_sch]
2023-03-13 Onderzoek ssr/mosfet/relais
2023-03-20 update docs
    [BestellijstV1.xlsx, BestellijstV2.xlsx]
2023-03-20 strrommeting + libraries pcb + schema
    [pcb_PoAB.kicad_pcb, pcb_PoAB.kicad_sch]
2023-04-06 schema en pcb voor lichtsmeter en base
    [ACS712ELCTR-05B-T.step, L7805CV.step, lichtsensor.kicad_pcb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]
2023-04-09 pcb lichsensor toegevoegd
    [pcb_PoAB.kicad_sch]
2023-04-16 lichtmetingen en voltage metingen toegevoegd
    [pcb_PoAB.kicad_sch]
2023-04-16 spanningsmeter aangepast
    [pcb_PoAB.kicad_sch]
2023-04-17 pcb gemaakt
    [pcb_PoAB.kicad_pcb, pcb_PoAB.kicad_sch]
2023-04-24 printplaat aangepast
2023-04-24 spannings meting en bord spanning aangepast pcb en schema
    [pcb_PoAB.kicad_pcb, pcb_PoAB.kicad_sch]
2023-04-25 PCB en schema spanning en stroommetingen aangepast
    [pcb_PoAB.kicad_pcb, pcb_PoAB.kicad_sch]
2023-04-25 pcb en spanningsmeting
2023-05-09 stroometingen en zips
    [bestellijst Voeding en Connectors.xlsx, pcb_PoAB.kicad_sch]
2023-05-09 stroommeting met I2C
2023-05-15 schema baseplate aangepast
    [ADS1115.step, pcb_PoAB.kicad_sch]
2023-05-15 pcb baseplate aangepast
    [pcb_PoAB.kicad_pcb, pcb_PoAB.kicad_sch]
2023-05-17 pcb zip gemaakt
    [lichtsensor.kicad_sch, pcb_PoAB.kicad_pcb, pcb_PoAB.kicad_sch]
2023-05-24 PCB track width adjusted
    [pcb_PoAB.kicad_pcb]
2023-05-30 printplaat baseplate tracks aangepast
    [pcb_PoAB.kicad_pcb]
2023-06-05 cleanup github
    [ACS712ELCTR-05B-T.step, ADS1115.step, IOT_PROJECT_TEMT6000.kicad_pcb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]
2023-06-07 printplaat en lichtmeter aangepast
    [lichtsensor.kicad_pcb, pcb_PoAB.kicad_pcb]
2023-06-07 pcb baseplate en docs aangepast
    [pcb_PoAB.kicad_pcb, pcb_PoAB.kicad_sch]
2023-06-07 pcb lichtsensor aangepast
    [lichtsensor.kicad_sch]
